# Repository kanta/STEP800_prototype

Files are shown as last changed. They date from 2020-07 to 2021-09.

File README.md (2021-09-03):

# STEP800_prototype

This repository has been retained for data storage, but is no longer being updated.

Please visit https://github.com/ponoor/STEP800.

---

STEP800

8 axis stepper motor driver board which can control over Ethernet. The current firmware is based on [Open Sound Control](http://opensoundcontrol.org/) protocol.
[Arduino Zero](https://www.arduino.cc/en/Guide/ArduinoZero) and official [Ethernet library](https://www.arduino.cc/en/reference/ethernet) compatible.

Stepper driver chips are STMicroelectronics's [L6470](https://www.st.com/en/motor-drivers/l6470.html) which provide most of functionalities as a stepper driver.

# Repository Contents

# Documentation

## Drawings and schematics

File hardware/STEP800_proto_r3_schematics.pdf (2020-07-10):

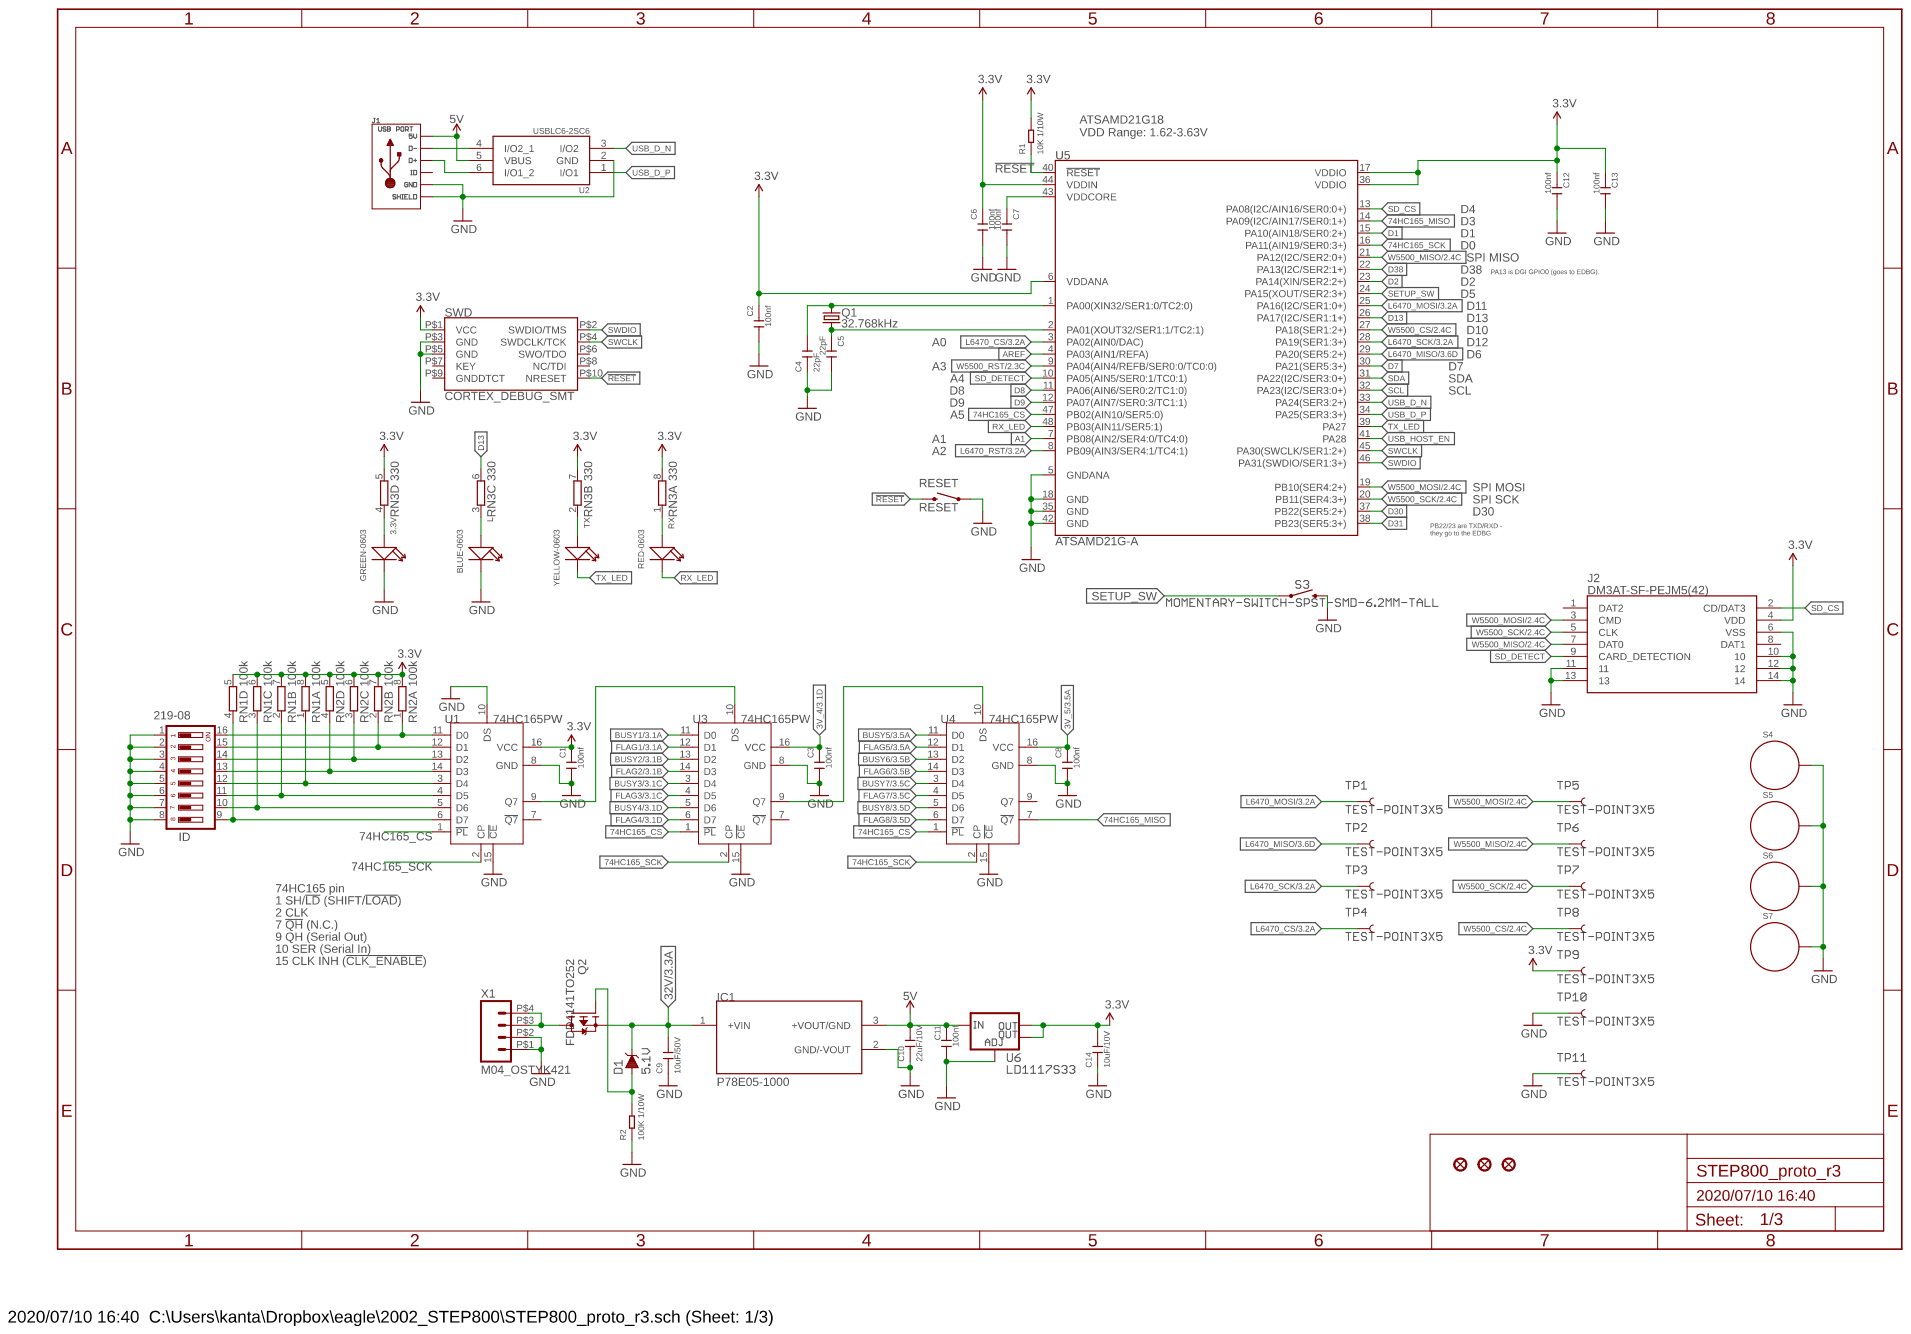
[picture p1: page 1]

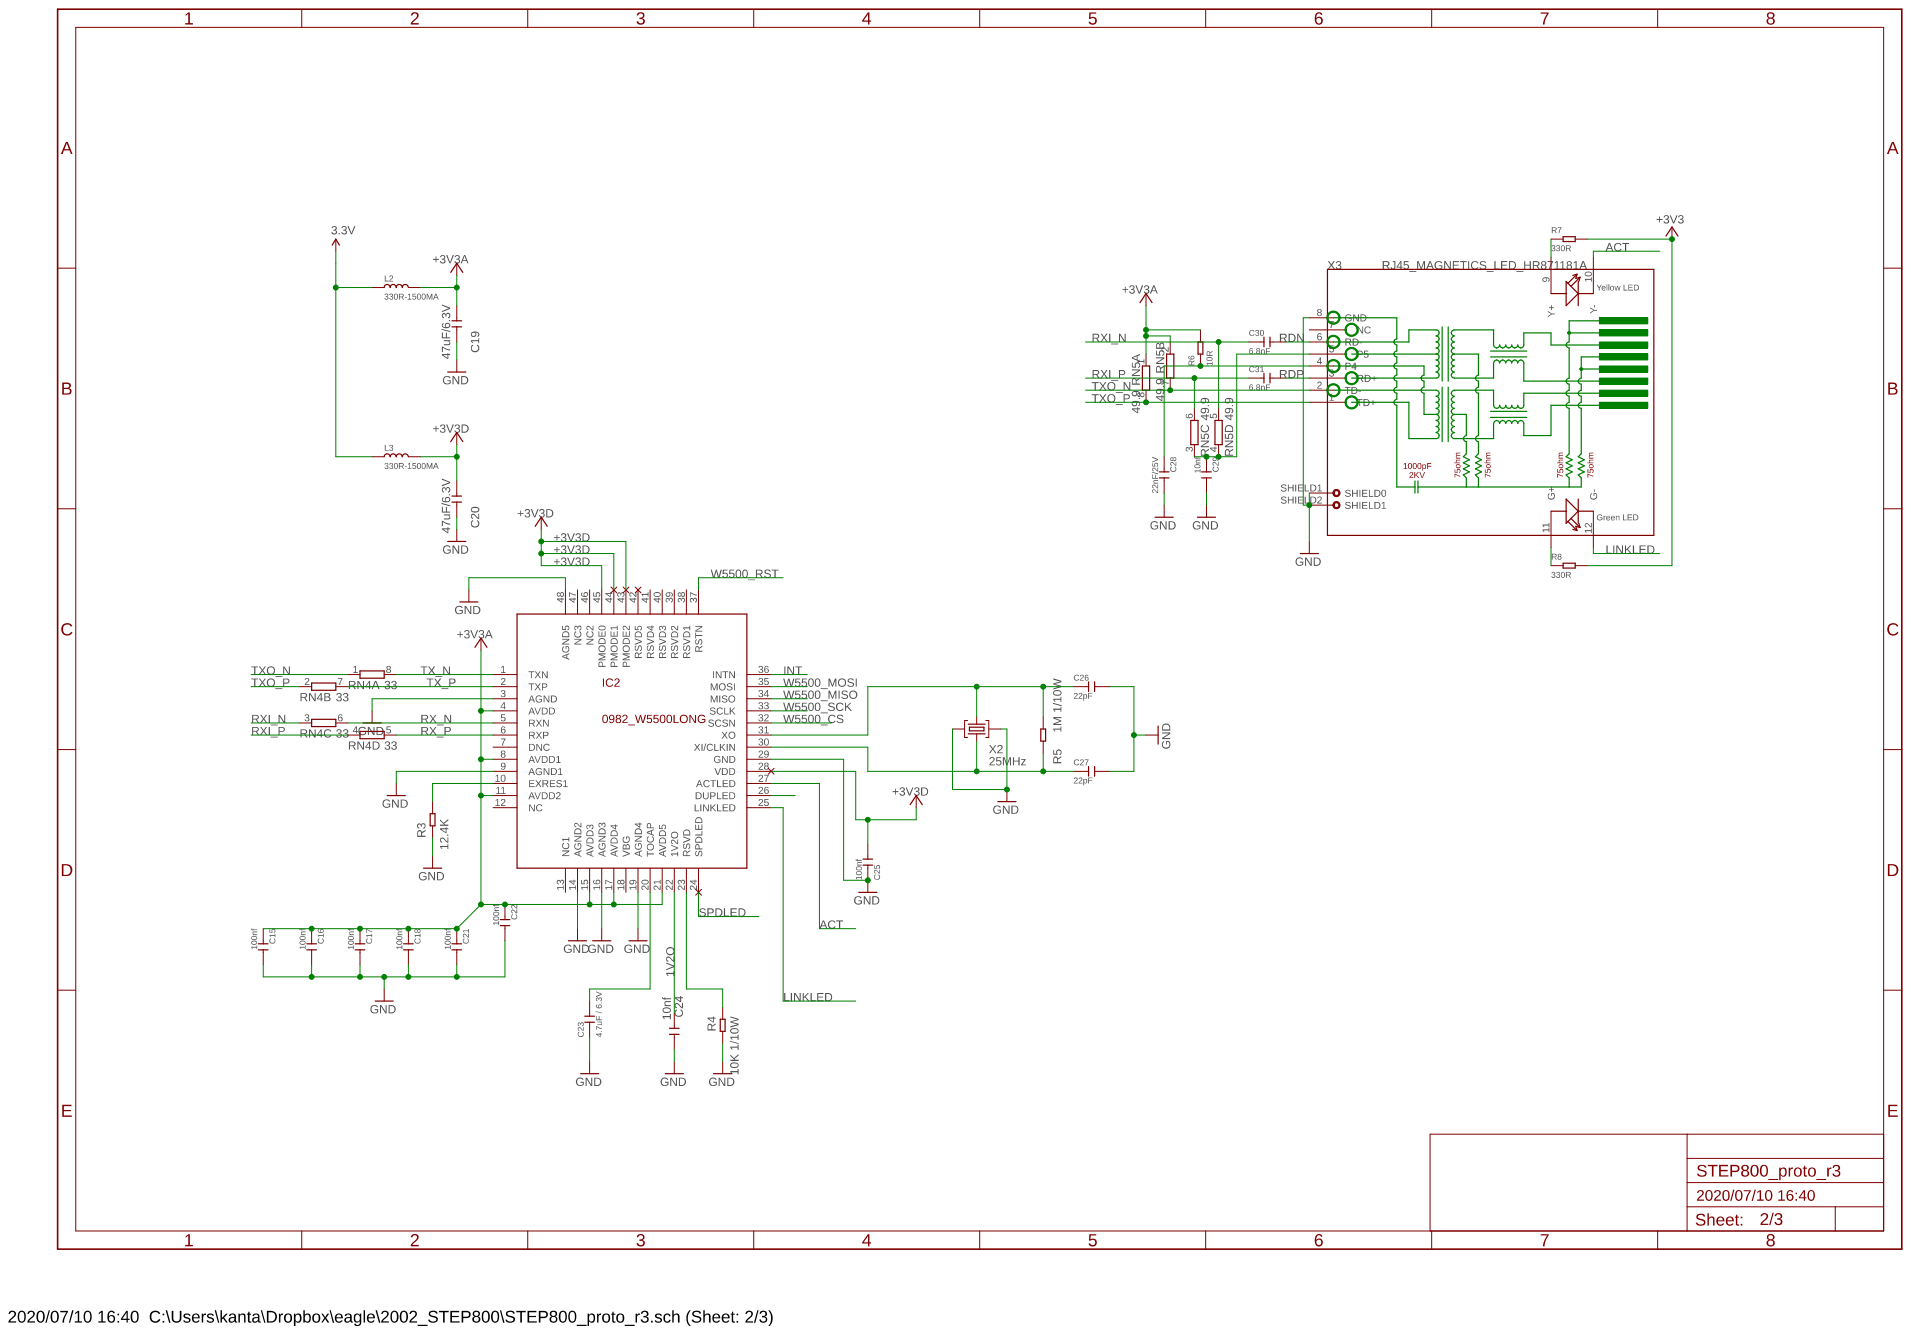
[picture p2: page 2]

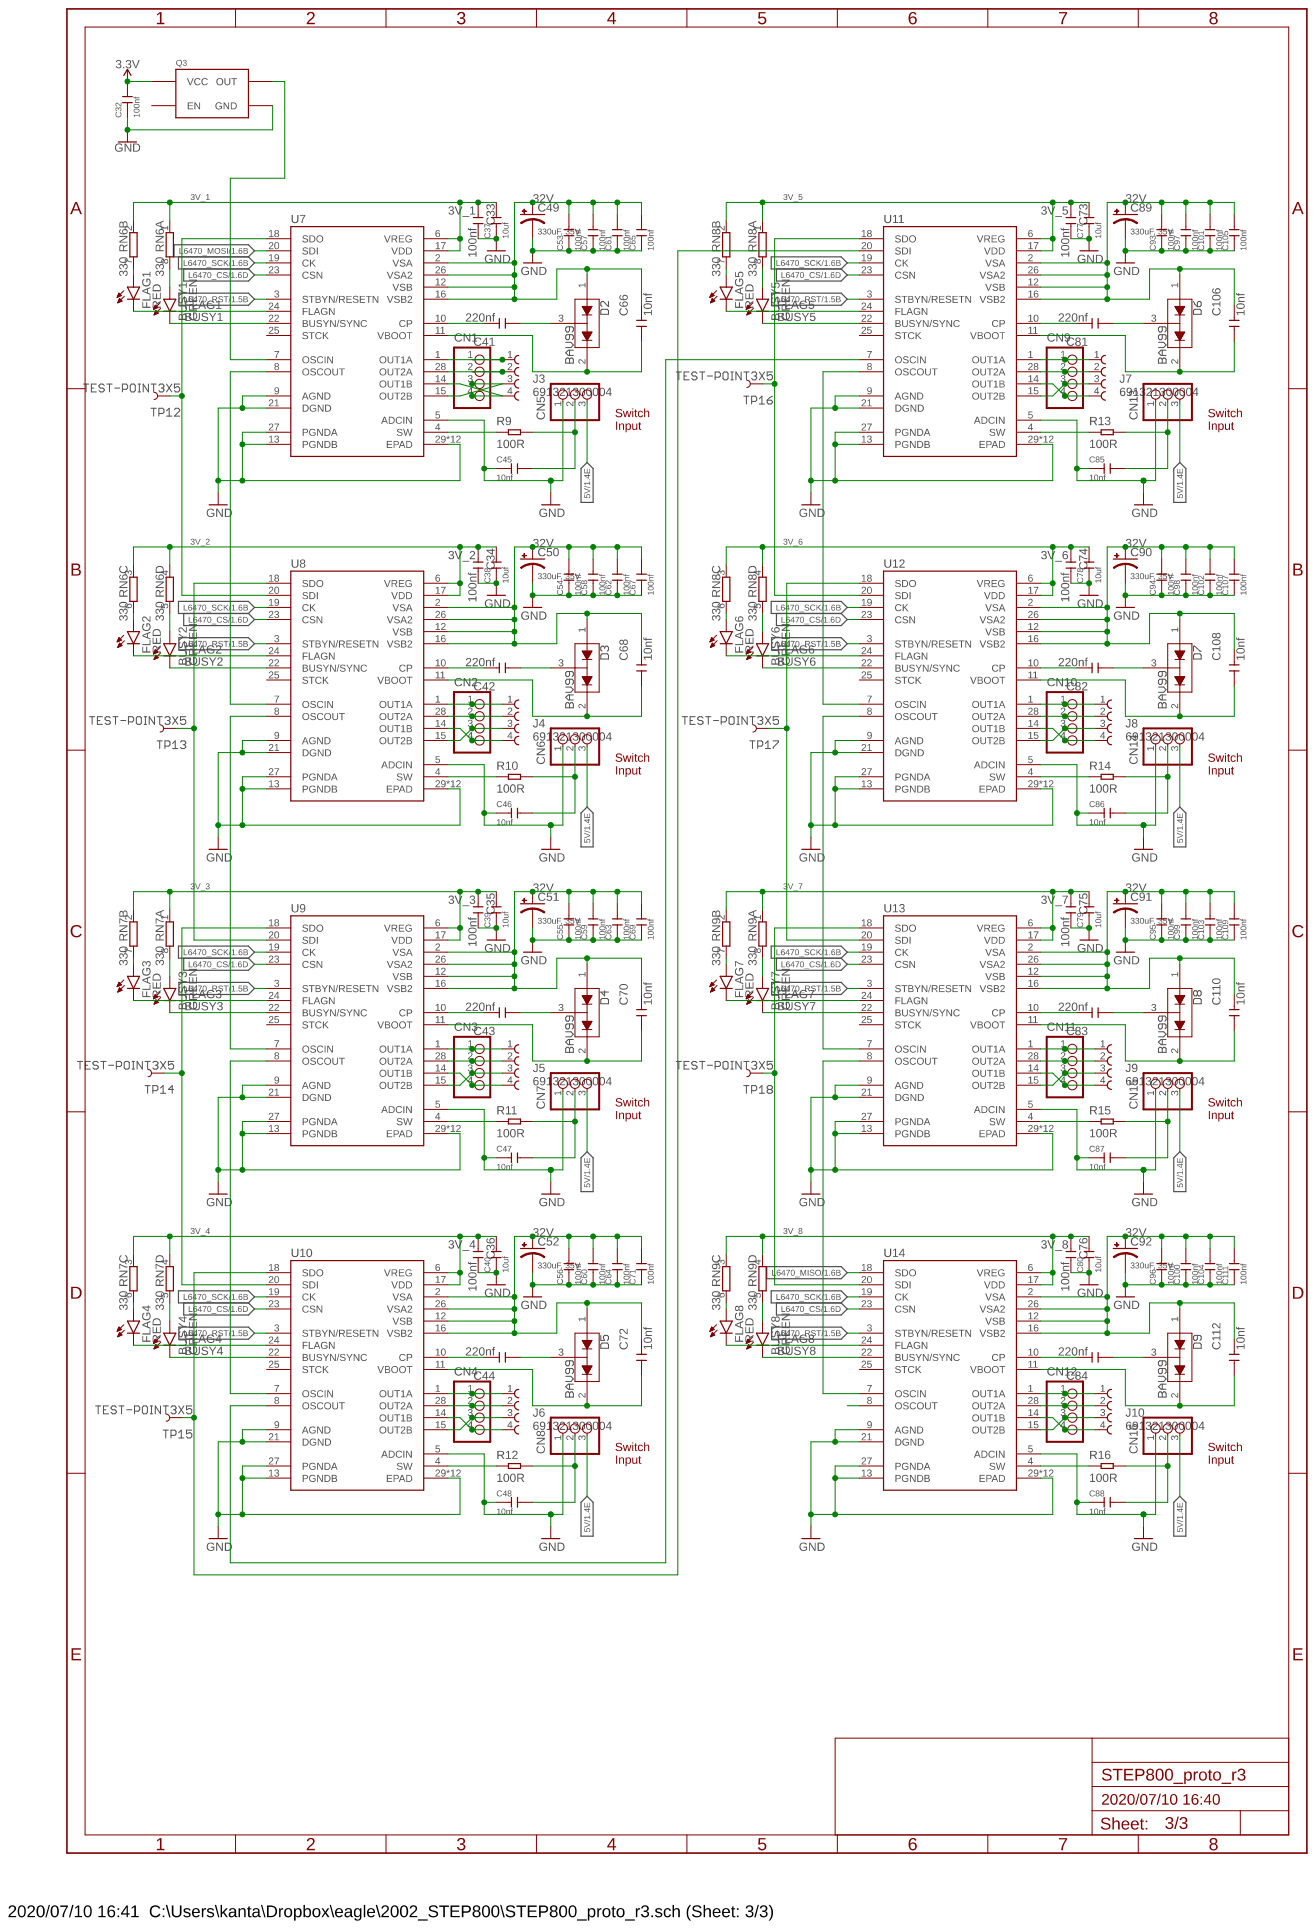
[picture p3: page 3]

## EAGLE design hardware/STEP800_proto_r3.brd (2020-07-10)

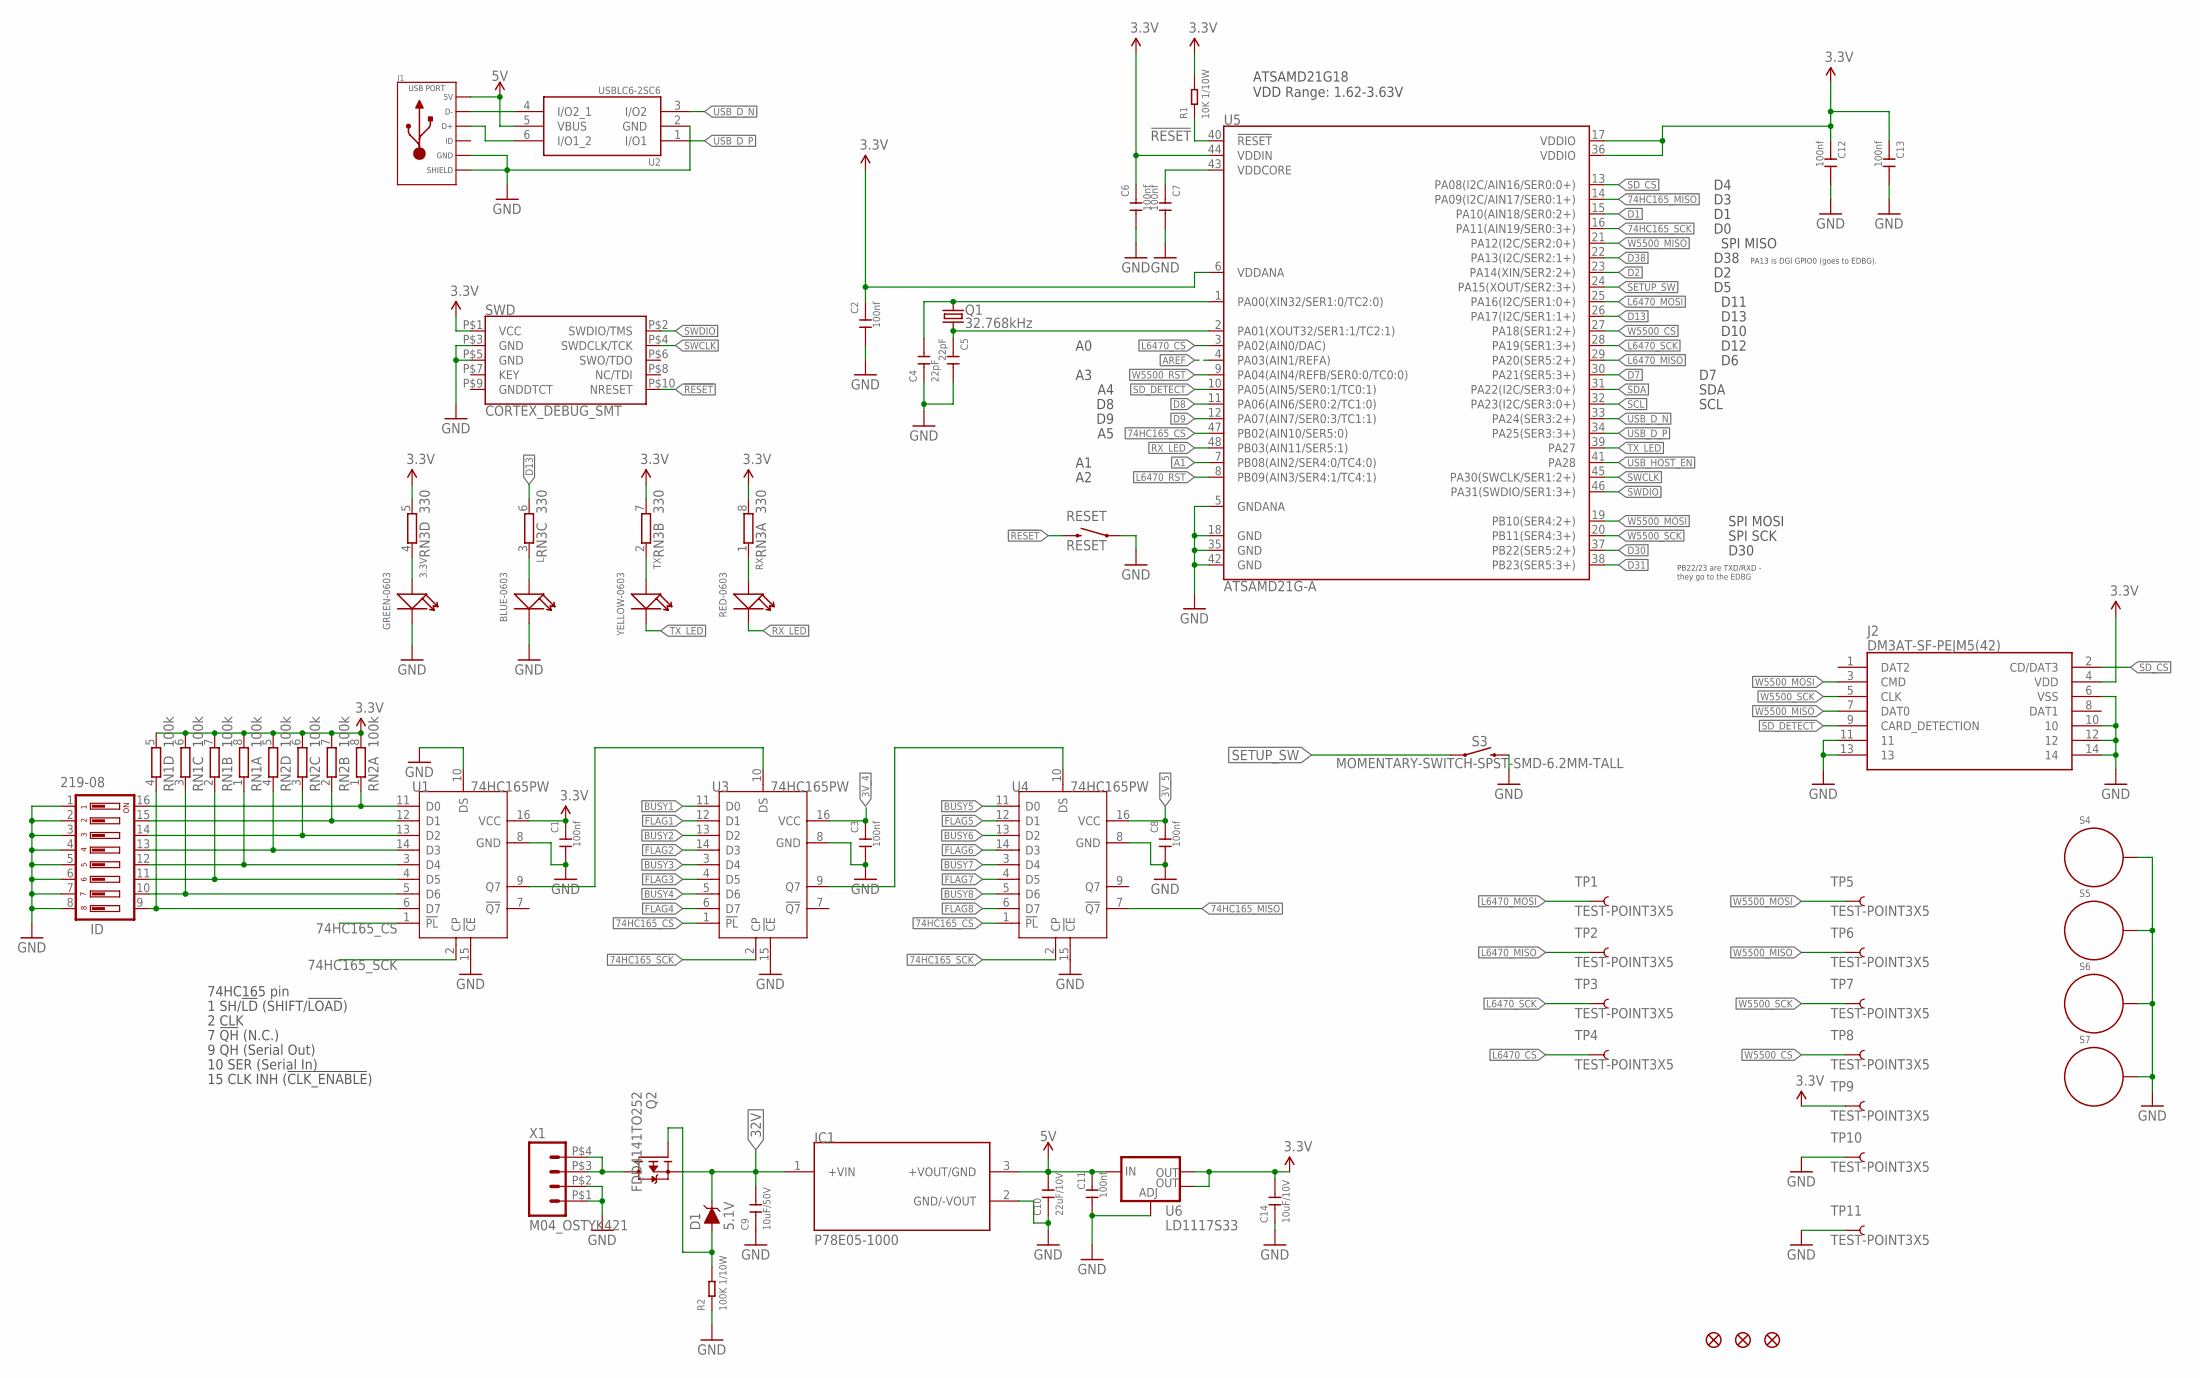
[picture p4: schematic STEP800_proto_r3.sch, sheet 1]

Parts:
3.3V: GREEN-0603; LED-0603
C1, C2, C3, C6, C7, C8, C11, C12, C13: 100nf; C0402
C4, C5: 22pF; C0402
C9: 10uF/50V; C1206
C10: 22uF/10V; C1206
C14: 10uF/10V; C0805
D1: 5.1V; SOD-323
FD1, FD2, FD3: FIDUCIAL1X2; FIDUCIAL-1X2
IC1: P78E05-1000; CONV_P78E05-1000
ID: 219-08; CTS-219-08
J1: USB_MICRO_10118193-0001LF; MICROUSB-FCI-PBAN
J2: DM3AT-SF-PEJM5(42); DM3ATSFPEJM542
L: BLUE-0603; LED-0603
Q1: 32.768kHz; FC-135
Q2: FDD4141TO252; TO252
R1: 10K 1/10W; R0603
R2: 100K 1/10W; R0603
RESET: RESET; TACTILE-SWITCH-SMD
RN1, RN2: 100k; CAY16_LONG_W
RN3: 330; CAY16_LONG_W
RX: RED-0603; LED-0603
S3: MOMENTARY-SWITCH-SPST-SMD-6.2MM-TALL; TACTILE_SWITCH_SMD_6.2MM_TALL
S4, S5, S6, S7: STANDOFF_ELECTRICAL; STANDOFF-ELECTRICAL
SWD: CORTEX_DEBUG_SMT; 20021121-00010C4LF
TP1, TP2, TP3, TP4, TP5, TP6, TP7, TP8, TP9, TP10, TP11: TEST-POINT3X5; PAD.03X.05
TX: YELLOW-0603; LED-0603
U1, U3, U4: 74HC165PW; TSSOP16
U2: USBLC6-2SC6; SOT23-6L
U5: ATSAMD21G-A; TQFP-48
U6: LD1117S33; SOT223
X1: M04_OSTYK421; OSTYK42104030

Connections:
3.3V: C1.1, C2.1, C6.1, C12.1, C13.1, C14.2, J2.4 (VDD), R1.2, RN1.5 (2), RN1.6 (2), RN1.7 (2), RN1.8 (2), RN2.5 (2), RN2.6 (2), RN2.7 (2), RN2.8 (2), RN3.5 (2), RN3.7 (2), RN3.8 (2), SWD.P$1 (VCC), TP9.P$1, U1.16 (VCC), U5.6 (VDDANA), U5.17 (VDDIO), U5.36 (VDDIO), U5.44 (VDDIN), U6.2 (OUT), U6.4 (OUT); also elsewhere on the board
3V_4: C3.1, U3.16 (VCC); also elsewhere on the board
3V_5: C8.1, U4.16 (VCC); also elsewhere on the board
5V: C10.2, C11.1, IC1.3 (+VOUT/GND), J1.1 (5V), U2.5 (VBUS), U6.3 (IN); also elsewhere on the board
32V: C9.2, D1.C, IC1.1 (+VIN), Q2.2 (S); also elsewhere on the board
74HC165_CS: U1.1 (!PL), U3.1 (!PL), U4.1 (!PL), U5.47 (PB02(AIN10/SER5:0))
74HC165_MISO: U4.7 (!Q7), U5.14 (PA09(I2C/AIN17/SER0:1+))
74HC165_SCK: U1.2 (CP), U3.2 (CP), U4.2 (CP), U5.16 (PA11(AIN19/SER0:3+))
!RESET: R1.1, RESET.3 (2), SWD.P$10 (NRESET), U5.40 (!RESET!)
A1: U5.7 (PB08(AIN2/SER4:0/TC4:0))
AREF: U5.4 (PA03(AIN1/REFA))
BUSY1: U3.11 (D0); also elsewhere on the board
BUSY2: U3.13 (D2); also elsewhere on the board
BUSY3: U3.3 (D4); also elsewhere on the board
BUSY4: U3.5 (D6); also elsewhere on the board
BUSY5: U4.11 (D0); also elsewhere on the board
BUSY6: U4.13 (D2); also elsewhere on the board
BUSY7: U4.3 (D4); also elsewhere on the board
BUSY8: U4.5 (D6); also elsewhere on the board
D1: U5.15 (PA10(AIN18/SER0:2+))
D2: U5.23 (PA14(XIN/SER2:2+))
D7: U5.30 (PA21(SER5:3+))
D8: U5.11 (PA06(AIN6/SER0:2/TC1:0))
D9: U5.12 (PA07(AIN7/SER0:3/TC1:1))
D13: RN3.6 (2), U5.26 (PA17(I2C/SER1:1+))
D30: U5.37 (PB22(SER5:2+))
D31: U5.38 (PB23(SER5:3+))
D38: U5.22 (PA13(I2C/SER2:1+))
D+1: J1.3 (D+), U2.6 (I/O1_2)
FLAG1: U3.12 (D1); also elsewhere on the board
FLAG2: U3.14 (D3); also elsewhere on the board
FLAG3: U3.4 (D5); also elsewhere on the board
FLAG4: U3.6 (D7); also elsewhere on the board
FLAG5: U4.12 (D1); also elsewhere on the board
FLAG6: U4.14 (D3); also elsewhere on the board
FLAG7: U4.4 (D5); also elsewhere on the board
FLAG8: U4.6 (D7); also elsewhere on the board
GND: 3.3V.-, C1.2, C2.2, C3.2, C4.1, C5.2, C6.2, C7.2, C8.2, C9.1, C10.1, C11.2, C12.2, C13.2, C14.1, IC1.2 (GND/-VOUT), ID.1, ID.2, ID.3, ID.4, ID.5, ID.6, ID.7, ID.8, J1.5 (GND), J1.S1 (SLD), J1.S2 (SLD), J1.S3 (SLD), J1.S4 (SLD), J1.S5 (SLD), J1.S6 (SLD), J1.S7 (SLD), J1.S8 (SLD), J2.6 (VSS), J2.10, J2.11, J2.12, J2.13, J2.14, L.-, R2.1, RESET.1, S3.B2 (2), S4.P1, S5.P1, S6.P1, S7.P1, SWD.P$3 (GND), SWD.P$5 (GND), TP10.P$1, TP11.P$1, U1.8 (GND), U1.10 (DS), U1.15 (!CE), U2.2 (GND), U3.8 (GND), U3.15 (!CE), U4.8 (GND), U4.15 (!CE), U5.5 (GNDANA), U5.18 (GND), U5.35 (GND), U5.42 (GND), U6.1 (ADJ), X1.P$1 (1), X1.P$2 (2); also elsewhere on the board
L6470_CS: TP4.P$1, U5.3 (PA02(AIN0/DAC)); also elsewhere on the board
L6470_MISO: TP2.P$1, U5.29 (PA20(SER5:2+)); also elsewhere on the board
L6470_MOSI: TP1.P$1, U5.25 (PA16(I2C/SER1:0+)); also elsewhere on the board
L6470_RST: U5.8 (PB09(AIN3/SER4:1/TC4:1)); also elsewhere on the board
L6470_SCK: TP3.P$1, U5.28 (PA19(SER1:3+)); also elsewhere on the board
unnamed: C4.2, Q1.P$2 (2), U5.1 (PA00(XIN32/SER1:0/TC2:0))
unnamed: ID.16, RN2.1, U1.11 (D0)
unnamed: D1.A, Q2.1 (G), R2.2
unnamed: ID.15, RN2.2 (1), U1.12 (D1)
unnamed: ID.14, RN2.3 (1), U1.13 (D2)
unnamed: C5.1, Q1.P$1 (1), U5.2 (PA01(XOUT32/SER1:1/TC2:1))
unnamed: U1.9 (Q7), U3.10 (DS)
unnamed: RN3.1, RX.+
unnamed: ID.13, RN2.4 (1), U1.14 (D3)
unnamed: ID.12, RN1.1, U1.3 (D4)
unnamed: ID.11, RN1.2 (1), U1.4 (D5)
unnamed: RN3.2 (1), TX.+
unnamed: L.+, RN3.3 (1)
unnamed: 3.3V.+, RN3.4 (1)
unnamed: J1.2 (D-), U2.4 (I/O2_1)
unnamed: ID.10, RN1.3 (1), U1.5 (D6)
unnamed: U3.9 (Q7), U4.10 (DS)
unnamed: ID.9, RN1.4 (1), U1.6 (D7)
RX_LED: RX.-, U5.48 (PB03(AIN11/SER5:1))
SCL: U5.32 (PA23(I2C/SER3:0+))
SDA: U5.31 (PA22(I2C/SER3:0+))
SD_CS: J2.2 (CD/DAT3), U5.13 (PA08(I2C/AIN16/SER0:0+))
SD_DETECT: J2.9 (CARD_DETECTION), U5.10 (PA05(AIN5/SER0:1/TC0:1))
SETUP_SW: S3.A2 (1), U5.24 (PA15(XOUT/SER2:3+))
SWCLK: SWD.P$4 (SWDCLK/TCK), U5.45 (PA30(SWCLK/SER1:2+))
SWDIO: SWD.P$2 (SWDIO/TMS), U5.46 (PA31(SWDIO/SER1:3+))
TX_LED: TX.-, U5.39 (PA27)
USB_D_N: U2.3 (I/O2), U5.33 (PA24(SER3:2+))
USB_D_P: U2.1 (I/O1), U5.34 (PA25(SER3:3+))
USB_HOST_EN: U5.41 (PA28)
VDDCORE1: C7.1, U5.43 (VDDCORE)
VRAW: Q2.3 (D), X1.P$3 (3), X1.P$4 (4)
W5500_CS: TP8.P$1, U5.27 (PA18(SER1:2+)); also elsewhere on the board
W5500_MISO: J2.7 (DAT0), TP6.P$1, U5.21 (PA12(I2C/SER2:0+)); also elsewhere on the board
W5500_MOSI: J2.3 (CMD), TP5.P$1, U5.19 (PB10(SER4:2+)); also elsewhere on the board
W5500_RST: U5.9 (PA04(AIN4/REFB/SER0:0/TC0:0)); also elsewhere on the board
W5500_SCK: J2.5 (CLK), TP7.P$1, U5.20 (PB11(SER4:3+)); also elsewhere on the board

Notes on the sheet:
PB22/23 are TXD/RXD - they go to the EDBG
PA13 is DGI GPIO0 (goes to EDBG).
ATSAMD21G18 VDD Range: 1.62-3.63V
D30
D12
D10
D11
D13
D38
SPI MISO
SPI MOSI
SPI SCK
SDA
SCL
1 SH/!LD! (SHIFT/!LOAD!)
2 CLK
7 !QH! (N.C.)
9 QH (Serial Out)
10 SER (Serial In)
15 CLK INH (!CLK_ENABLE!)
74HC165 pin

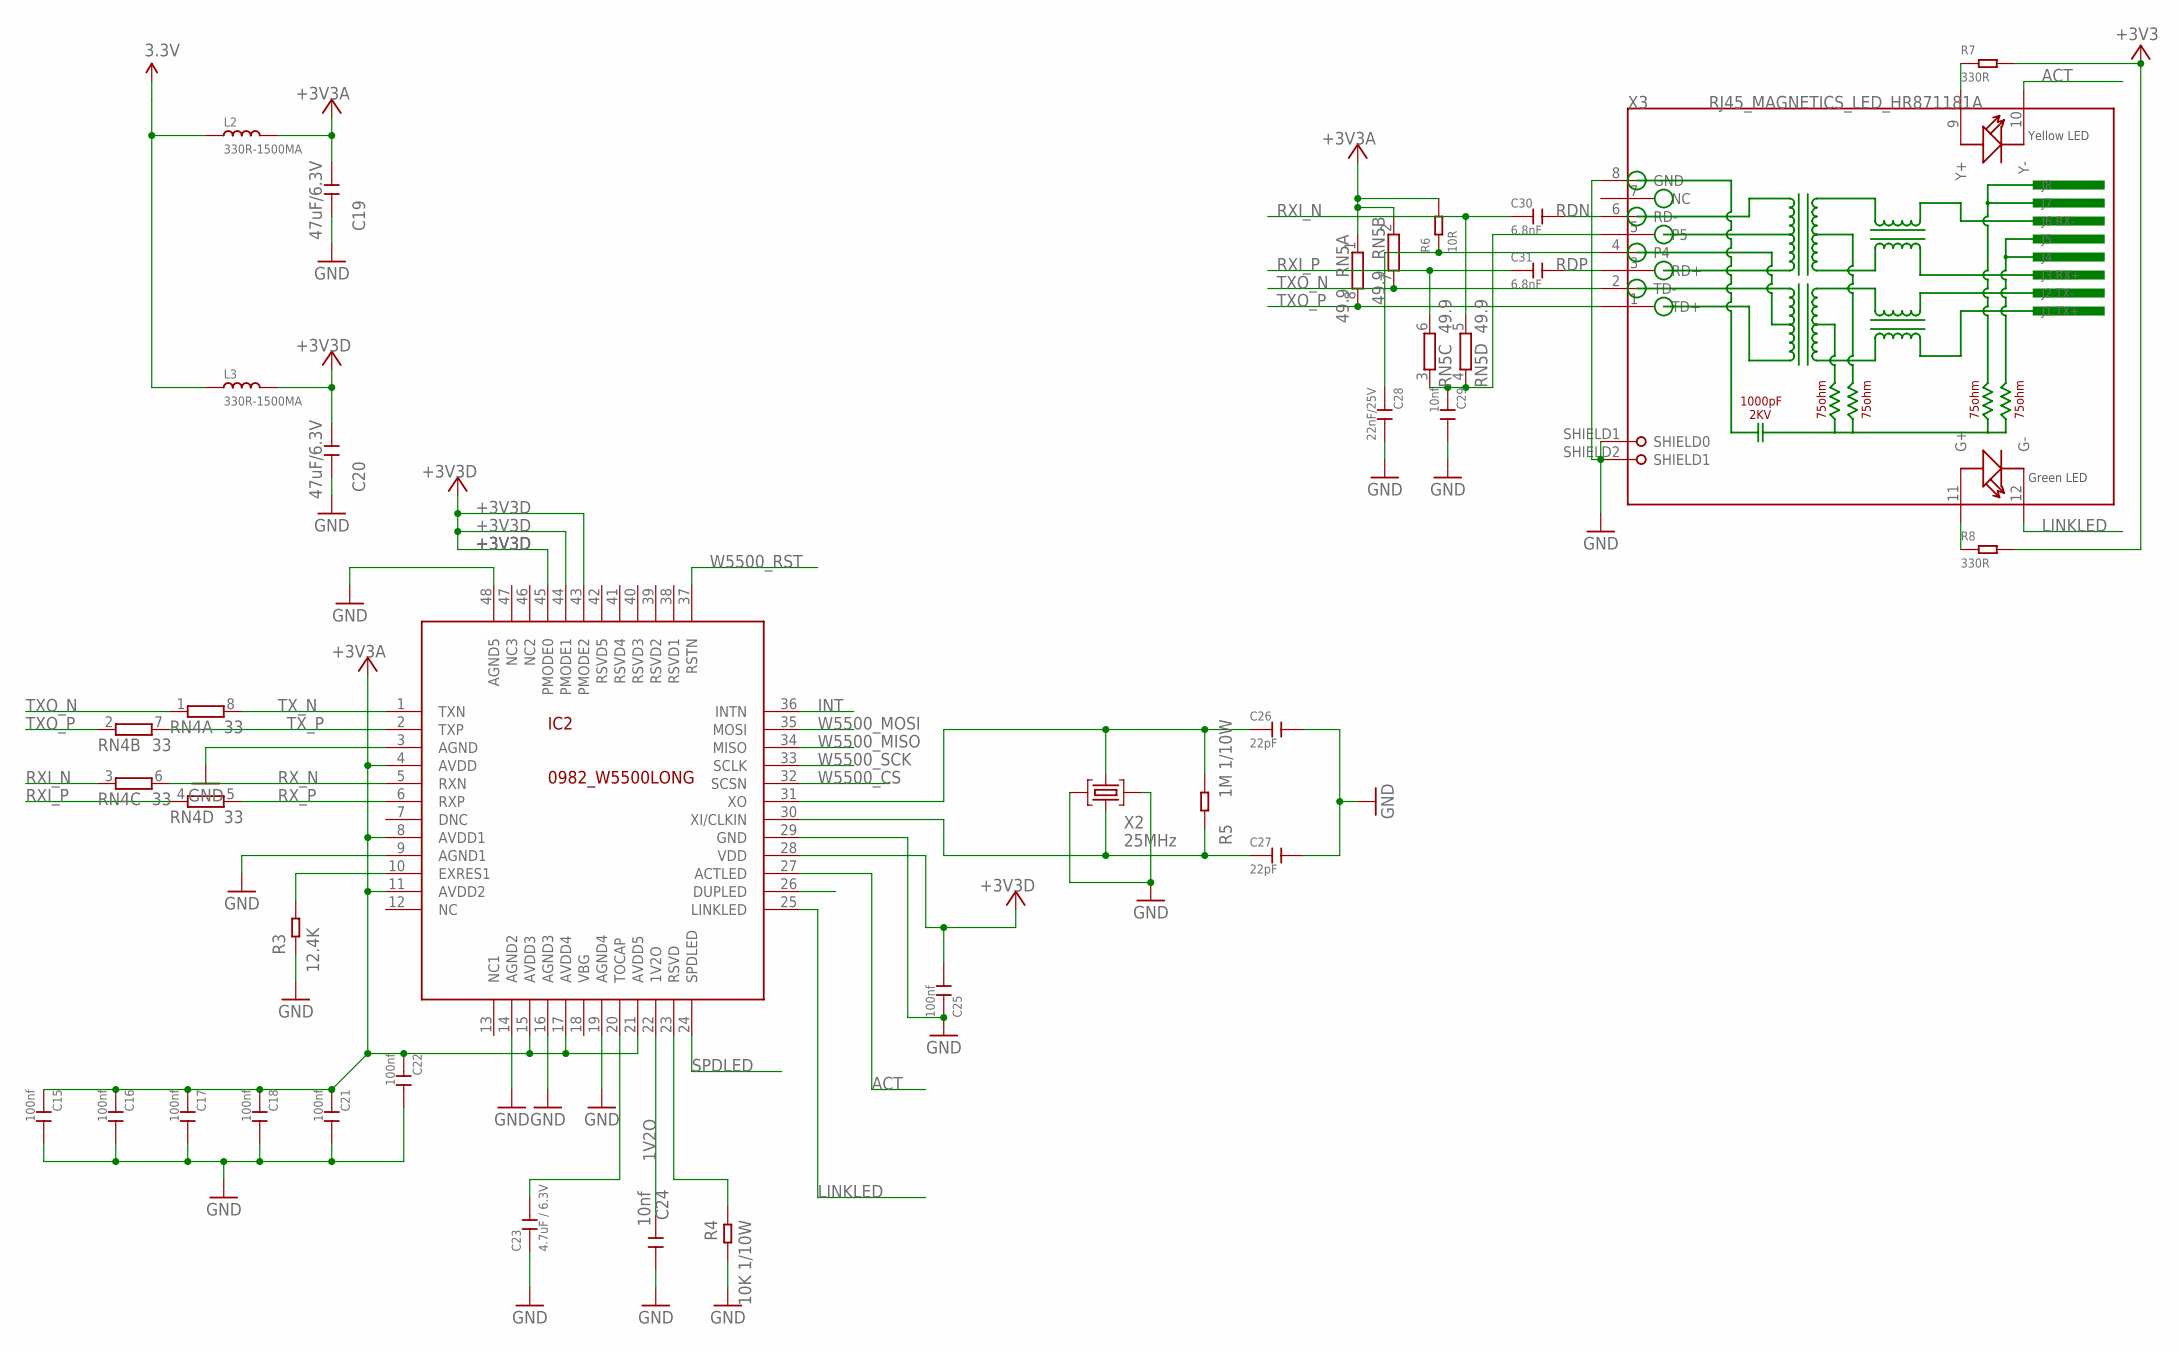
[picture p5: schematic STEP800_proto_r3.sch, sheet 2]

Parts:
C15, C16, C17, C18, C21, C22, C25: 100nf; C0402
C19, C20: 47uF/6.3V; C1206
C23: 4.7uF / 6.3V; C0603
C24, C29: 10nf; C0402
C26, C27: 22pF; C0402
C28: 22nF/25V; C0402
C30, C31: 6.8nF; C0402
IC2: 0982_W5500LONG; TQFP48-LONG
L2, L3: 330R-1500MA; L0805
R3: 12.4K; R0603
R4: 10K 1/10W; R0603
R5: 1M 1/10W; R0603
R6: 10R; R0603
R7, R8: 330R; R0603
RN4: 33; CAY16_LONG_W
RN5: 49.9; CAY16_LONG_W
X2: 25MHz; CRYSTAL-3.2-2.5
X3: RJ45_MAGNETICS_LED_HR871181A; HR871181A

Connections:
1V2O: C24.2, IC2.22 (1V2O)
3.3V: L2.1, L3.1, R7.2, R8.2; also elsewhere on the board
+3V3A: C15.1, C16.1, C17.1, C18.1, C19.1, C21.1, C22.1, IC2.4 (AVDD), IC2.8 (AVDD1), IC2.11 (AVDD2), IC2.15 (AVDD3), IC2.17 (AVDD4), IC2.21 (AVDD5), L2.2, R6.2, RN5.1, RN5.2 (1)
+3V3D: C20.1, C25.2, IC2.28 (VDD), IC2.43 (PMODE2), IC2.44 (PMODE1), IC2.45 (PMODE0), L3.2
ACT: IC2.27 (ACTLED), X3.10 (Y-)
FDXLED1: IC2.26 (DUPLED)
GND: C15.2, C16.2, C17.2, C18.2, C19.2, C20.2, C21.2, C22.2, C23.1, C24.1, C25.1, C26.2, C27.2, C28.2, C29.2, IC2.3 (AGND), IC2.9 (AGND1), IC2.14 (AGND2), IC2.16 (AGND3), IC2.19 (AGND4), IC2.29 (GND), IC2.48 (AGND5), R3.1, R4.1, X2.2 (GND), X2.4 (GND), X3.8 (GND), X3.SHIELD1 (SHIELD0), X3.SHIELD2 (SHIELD1); also elsewhere on the board
INT: IC2.36 (INTN)
LINKLED: IC2.25 (LINKLED), X3.12 (G-)
unnamed: C26.1, IC2.31 (XO), R5.1, X2.3 (C2)
unnamed: IC2.23 (RSVD), R4.2
unnamed: IC2.10 (EXRES1), R3.2
unnamed: C23.2, IC2.20 (TOCAP)
unnamed: C28.1, R6.1, X3.4
unnamed: C29.1, RN5.3 (1), RN5.4 (1), X3.5
unnamed: R7.1, X3.9 (Y+)
unnamed: R8.1, X3.11 (G+)
NC: IC2.12 (NC)
OSC2E1: C27.1, IC2.30 (XI/CLKIN), R5.2, X2.1 (C1)
RDN: C30.2, X3.6 (RD-)
RDP: C31.2, X3.3 (RD+)
RSVD1: IC2.38 (RSVD1)
RSVD2: IC2.39 (RSVD2)
RSVD3: IC2.40 (RSVD3)
RXI_N: C30.1, RN4.3 (1), RN5.5 (2)
RXI_P: C31.1, RN4.4 (1), RN5.6 (2)
RX_N: IC2.5 (RXN), RN4.6 (2)
RX_P: IC2.6 (RXP), RN4.5 (2)
SPDLED: IC2.24 (SPDLED)
TXO_N: RN4.1, RN5.7 (2), X3.2 (TD-)
TXO_P: RN4.2 (1), RN5.8 (2), X3.1 (TD+)
TX_N: IC2.1 (TXN), RN4.8 (2)
TX_P: IC2.2 (TXP), RN4.7 (2)
W5500_CS: IC2.32 (SCSN); also elsewhere on the board
W5500_MISO: IC2.34 (MISO); also elsewhere on the board
W5500_MOSI: IC2.35 (MOSI); also elsewhere on the board
W5500_RST: IC2.37 (RSTN); also elsewhere on the board
W5500_SCK: IC2.33 (SCLK); also elsewhere on the board

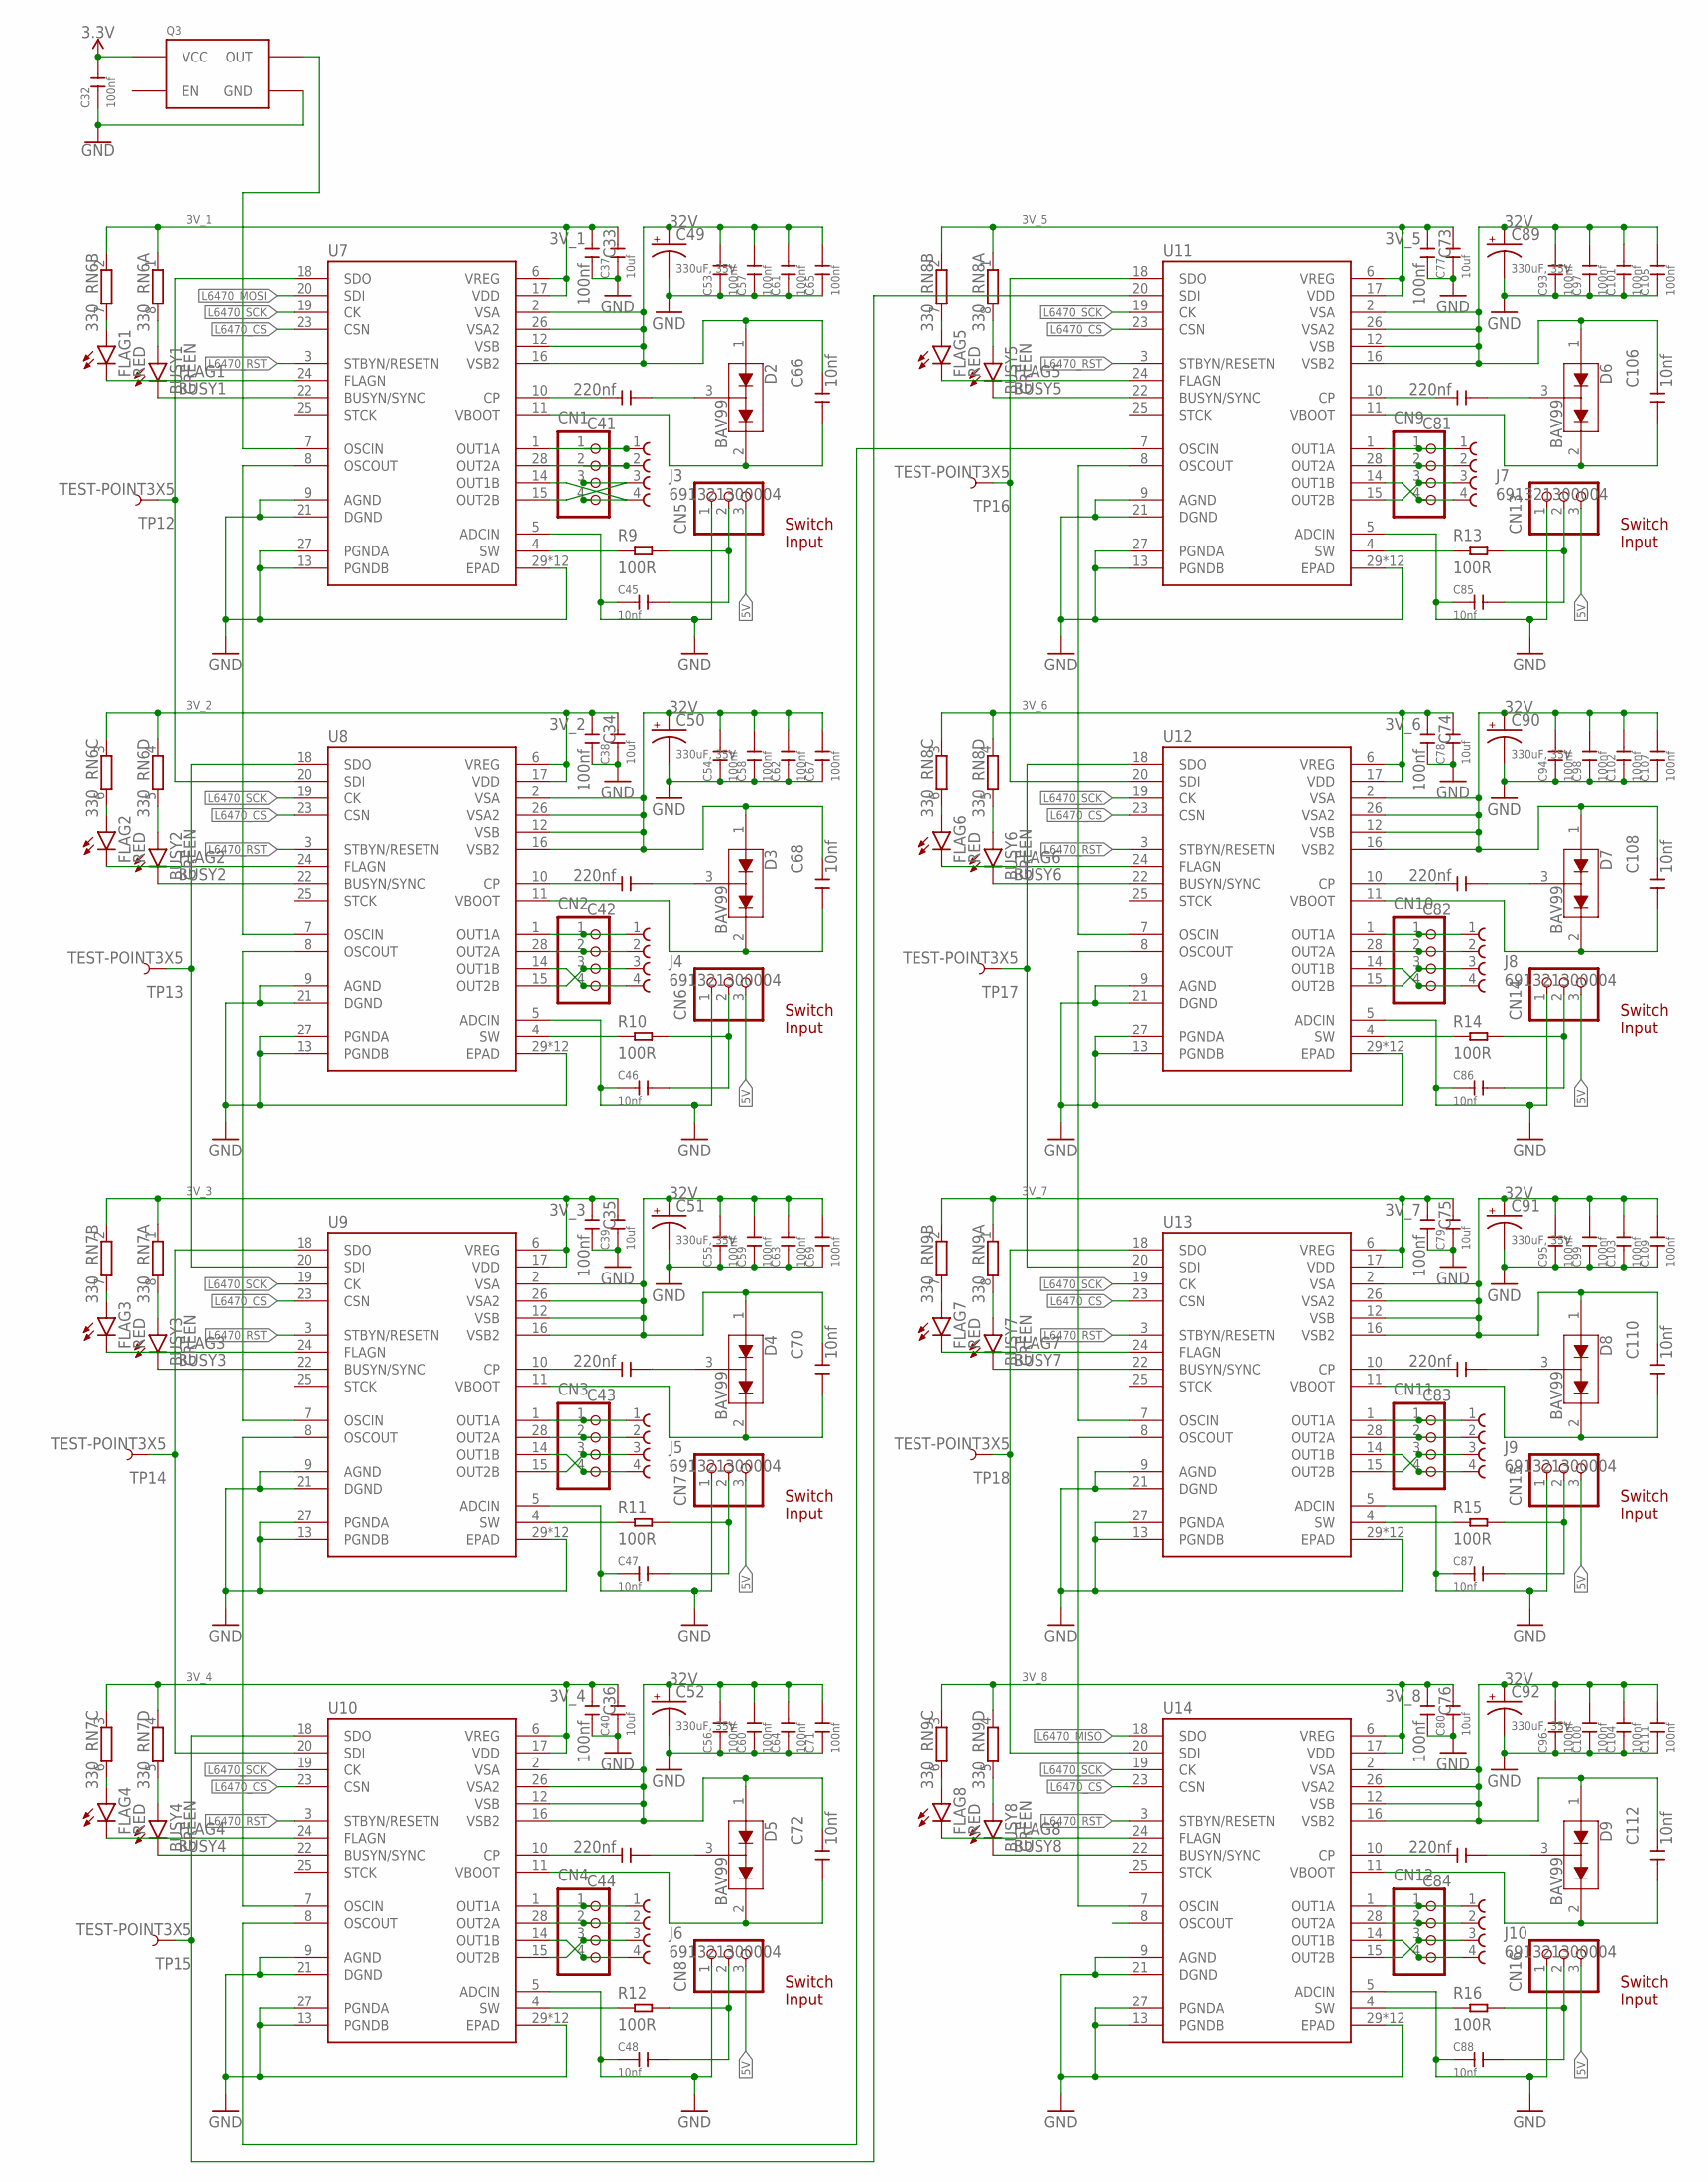
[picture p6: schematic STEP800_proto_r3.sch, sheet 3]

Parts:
BUSY1, BUSY2, BUSY3, BUSY4, BUSY5, BUSY6, BUSY7, BUSY8: GREEN; LED-0603
C32, C33, C34, C35, C36, C73, C74, C75, C76: 100nf; C0402
C37, C38, C39, C40, C77, C78, C79, C80: 10uf; C0805
C41, C42, C43, C44, C81, C82, C83, C84: 220nf; C0603
C45, C46, C47, C48, C66, C68, C70, C72, C85, C86, C87, C88, C106, C108, C110, C112: 10nf; C0402
C49, C50, C51, C52, C89, C90, C91, C92: 330uF, 35V; NICHICON_D10
C53, C54, C55, C56, C57, C58, C59, C60, C61, C62, C63, C64, C65, C67, C69, C71, C93, C94, C95, C96, C97, C98, C99, C100, C101, C102, C103, C104, C105, C107, C109, C111: 100nf; C0603
CN1, CN2, CN3, CN4, CN9, CN10, CN11, CN12: B4B-XASK-1
CN5, CN6, CN7, CN8, CN13, CN14, CN15, CN16: B3B-XASK-1
D2, D3, D4, D5, D6, D7, D8, D9: BAV99; SOT23-3
FLAG1, FLAG2, FLAG3, FLAG4, FLAG5, FLAG6, FLAG7, FLAG8: RED; LED-0603
J3, J4, J5, J6, J7, J8, J9, J10: 691321300004
Q3: CRYSTAL_OSC_SG5032; SG5032
R9, R10, R11, R12, R13, R14, R15, R16: 100R; R0603
RN6, RN7, RN8, RN9: 330; CAY16_LONG_W
TP12, TP13, TP14, TP15, TP16, TP17, TP18: TEST-POINT3X5; PAD.03X.05
U7, U8, U9, U10, U11, U12, U13, U14: L6470_THERMALVIA; HTSSOP28_VIA

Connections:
3.3V: C32.2, Q3.4 (VCC); also elsewhere on the board
3V_1: C33.1, C37.2, RN6.1, RN6.2 (1), U7.6 (VREG), U7.17 (VDD)
3V_2: C34.1, C38.2, RN6.3 (1), RN6.4 (1), U8.6 (VREG), U8.17 (VDD)
3V_3: C35.1, C39.2, RN7.1, RN7.2 (1), U9.6 (VREG), U9.17 (VDD)
3V_4: C36.1, C40.2, RN7.3 (1), RN7.4 (1), U10.6 (VREG), U10.17 (VDD); also elsewhere on the board
3V_5: C73.1, C77.2, RN8.1, RN8.2 (1), U11.6 (VREG), U11.17 (VDD); also elsewhere on the board
3V_6: C74.1, C78.2, RN8.3 (1), RN8.4 (1), U12.6 (VREG), U12.17 (VDD)
3V_7: C75.1, C79.2, RN9.1, RN9.2 (1), U13.6 (VREG), U13.17 (VDD)
3V_8: C76.1, C80.2, RN9.3 (1), RN9.4 (1), U14.6 (VREG), U14.17 (VDD)
5V: CN5.3, CN6.3, CN7.3, CN8.3, CN13.3, CN14.3, CN15.3, CN16.3; also elsewhere on the board
32V: C49.+, C50.+, C51.+, C52.+, C53.2, C54.2, C55.2, C56.2, C57.2, C58.2, C59.2, C60.2, C61.2, C62.2, C63.2, C64.2, C65.2, C66.2, C67.2, C68.2, C69.2, C70.2, C71.2, C72.2, C89.+, C90.+, C91.+, C92.+, C93.2, C94.2, C95.2, C96.2, C97.2, C98.2, C99.2, C100.2, C101.2, C102.2, C103.2, C104.2, C105.2, C106.2, C107.2, C108.2, C109.2, C110.2, C111.2, C112.2, D2.1 (A1), D3.1 (A1), D4.1 (A1), D5.1 (A1), D6.1 (A1), D7.1 (A1), D8.1 (A1), D9.1 (A1), U7.2 (VSA), U7.12 (VSB), U7.16 (VSB2), U7.26 (VSA2), U8.2 (VSA), U8.12 (VSB), U8.16 (VSB2), U8.26 (VSA2), U9.2 (VSA), U9.12 (VSB), U9.16 (VSB2), U9.26 (VSA2), U10.2 (VSA), U10.12 (VSB), U10.16 (VSB2), U10.26 (VSA2), U11.2 (VSA), U11.12 (VSB), U11.16 (VSB2), U11.26 (VSA2), U12.2 (VSA), U12.12 (VSB), U12.16 (VSB2), U12.26 (VSA2), U13.2 (VSA), U13.12 (VSB), U13.16 (VSB2), U13.26 (VSA2), U14.2 (VSA), U14.12 (VSB), U14.16 (VSB2), U14.26 (VSA2); also elsewhere on the board
BUSY1: BUSY1.C, U7.22 (BUSYN/SYNC); also elsewhere on the board
BUSY2: BUSY2.C, U8.22 (BUSYN/SYNC); also elsewhere on the board
BUSY3: BUSY3.C, U9.22 (BUSYN/SYNC); also elsewhere on the board
BUSY4: BUSY4.C, U10.22 (BUSYN/SYNC); also elsewhere on the board
BUSY5: BUSY5.C, U11.22 (BUSYN/SYNC); also elsewhere on the board
BUSY6: BUSY6.C, U12.22 (BUSYN/SYNC); also elsewhere on the board
BUSY7: BUSY7.C, U13.22 (BUSYN/SYNC); also elsewhere on the board
BUSY8: BUSY8.C, U14.22 (BUSYN/SYNC); also elsewhere on the board
FLAG1: FLAG1.C, U7.24 (FLAGN); also elsewhere on the board
FLAG2: FLAG2.C, U8.24 (FLAGN); also elsewhere on the board
FLAG3: FLAG3.C, U9.24 (FLAGN); also elsewhere on the board
FLAG4: FLAG4.C, U10.24 (FLAGN); also elsewhere on the board
FLAG5: FLAG5.C, U11.24 (FLAGN); also elsewhere on the board
FLAG6: FLAG6.C, U12.24 (FLAGN); also elsewhere on the board
FLAG7: FLAG7.C, U13.24 (FLAGN); also elsewhere on the board
FLAG8: FLAG8.C, U14.24 (FLAGN); also elsewhere on the board
GND: C32.1, C33.2, C34.2, C35.2, C36.2, C37.1, C38.1, C39.1, C40.1, C45.1, C46.1, C47.1, C48.1, C49.-, C50.-, C51.-, C52.-, C53.1, C54.1, C55.1, C56.1, C57.1, C58.1, C59.1, C60.1, C61.1, C62.1, C63.1, C64.1, C65.1, C67.1, C69.1, C71.1, C73.2, C74.2, C75.2, C76.2, C77.1, C78.1, C79.1, C80.1, C85.1, C86.1, C87.1, C88.1, C89.-, C90.-, C91.-, C92.-, C93.1, C94.1, C95.1, C96.1, C97.1, C98.1, C99.1, C100.1, C101.1, C102.1, C103.1, C104.1, C105.1, C107.1, C109.1, C111.1, CN5.1, CN6.1, CN7.1, CN8.1, CN13.1, CN14.1, CN15.1, CN16.1, Q3.2 (GND), U7.5 (ADCIN), U7.9 (AGND), U7.13 (PGNDB), U7.21 (DGND), U7.27 (PGNDA), U7.29 (EPAD), U7.VIA1 (EPAD), U7.VIA2 (EPAD), U7.VIA3 (EPAD), U7.VIA4 (EPAD), U7.VIA5 (EPAD), U7.VIA6 (EPAD), U7.VIA7 (EPAD), U7.VIA8 (EPAD), U7.VIA9 (EPAD), U7.VIA10 (EPAD), U7.VIA11 (EPAD), U8.5 (ADCIN), U8.9 (AGND), U8.13 (PGNDB), U8.21 (DGND), U8.27 (PGNDA), U8.29 (EPAD), U8.VIA1 (EPAD), U8.VIA2 (EPAD), U8.VIA3 (EPAD), U8.VIA4 (EPAD), U8.VIA5 (EPAD), U8.VIA6 (EPAD), U8.VIA7 (EPAD), U8.VIA8 (EPAD), U8.VIA9 (EPAD), U8.VIA10 (EPAD), U8.VIA11 (EPAD), U9.5 (ADCIN), U9.9 (AGND), U9.13 (PGNDB), U9.21 (DGND), U9.27 (PGNDA), U9.29 (EPAD), U9.VIA1 (EPAD), U9.VIA2 (EPAD), U9.VIA3 (EPAD), U9.VIA4 (EPAD), U9.VIA5 (EPAD), U9.VIA6 (EPAD), U9.VIA7 (EPAD), U9.VIA8 (EPAD), U9.VIA9 (EPAD), U9.VIA10 (EPAD), U9.VIA11 (EPAD), U10.5 (ADCIN), U10.9 (AGND), U10.13 (PGNDB), U10.21 (DGND), U10.27 (PGNDA), U10.29 (EPAD), U10.VIA1 (EPAD), U10.VIA2 (EPAD), U10.VIA3 (EPAD), U10.VIA4 (EPAD), U10.VIA5 (EPAD), U10.VIA6 (EPAD), U10.VIA7 (EPAD), U10.VIA8 (EPAD), U10.VIA9 (EPAD), U10.VIA10 (EPAD), U10.VIA11 (EPAD), U11.5 (ADCIN), U11.9 (AGND), U11.13 (PGNDB), U11.21 (DGND), U11.27 (PGNDA), U11.29 (EPAD), U11.VIA1 (EPAD), U11.VIA2 (EPAD), U11.VIA3 (EPAD), U11.VIA4 (EPAD), U11.VIA5 (EPAD), U11.VIA6 (EPAD), U11.VIA7 (EPAD), U11.VIA8 (EPAD), U11.VIA9 (EPAD), U11.VIA10 (EPAD), U11.VIA11 (EPAD), U12.5 (ADCIN), U12.9 (AGND), U12.13 (PGNDB), U12.21 (DGND), U12.27 (PGNDA), U12.29 (EPAD), U12.VIA1 (EPAD), U12.VIA2 (EPAD), U12.VIA3 (EPAD), U12.VIA4 (EPAD), U12.VIA5 (EPAD), U12.VIA6 (EPAD), U12.VIA7 (EPAD), U12.VIA8 (EPAD), U12.VIA9 (EPAD), U12.VIA10 (EPAD), U12.VIA11 (EPAD), U13.5 (ADCIN), U13.9 (AGND), U13.13 (PGNDB), U13.21 (DGND), U13.27 (PGNDA), U13.29 (EPAD), U13.VIA1 (EPAD), U13.VIA2 (EPAD), U13.VIA3 (EPAD), U13.VIA4 (EPAD), U13.VIA5 (EPAD), U13.VIA6 (EPAD), U13.VIA7 (EPAD), U13.VIA8 (EPAD), U13.VIA9 (EPAD), U13.VIA10 (EPAD), U13.VIA11 (EPAD), U14.5 (ADCIN), U14.9 (AGND), U14.13 (PGNDB), U14.21 (DGND), U14.27 (PGNDA), U14.29 (EPAD), U14.VIA1 (EPAD), U14.VIA2 (EPAD), U14.VIA3 (EPAD), U14.VIA4 (EPAD), U14.VIA5 (EPAD), U14.VIA6 (EPAD), U14.VIA7 (EPAD), U14.VIA8 (EPAD), U14.VIA9 (EPAD), U14.VIA10 (EPAD), U14.VIA11 (EPAD); also elsewhere on the board
L6470_CS: U7.23 (CSN), U8.23 (CSN), U9.23 (CSN), U10.23 (CSN), U11.23 (CSN), U12.23 (CSN), U13.23 (CSN), U14.23 (CSN); also elsewhere on the board
L6470_MISO: U14.18 (SDO); also elsewhere on the board
L6470_MOSI: U7.20 (SDI); also elsewhere on the board
L6470_RST: U7.3 (STBYN/RESETN), U8.3 (STBYN/RESETN), U9.3 (STBYN/RESETN), U10.3 (STBYN/RESETN), U11.3 (STBYN/RESETN), U12.3 (STBYN/RESETN), U13.3 (STBYN/RESETN), U14.3 (STBYN/RESETN); also elsewhere on the board
L6470_SCK: U7.19 (CK), U8.19 (CK), U9.19 (CK), U10.19 (CK), U11.19 (CK), U12.19 (CK), U13.19 (CK), U14.19 (CK); also elsewhere on the board
unnamed: C41.2, U7.10 (CP)
unnamed: C41.1, D2.3 (COM)
unnamed: C66.1, D2.2 (C2), U7.11 (VBOOT)
unnamed: R9.1, U7.4 (SW)
unnamed: BUSY1.A, RN6.8 (2)
unnamed: FLAG1.A, RN6.7 (2)
unnamed: C45.2, CN5.2, R9.2
unnamed: CN1.1, J3.1, U7.1 (OUT1A)
unnamed: CN1.2, J3.2, U7.28 (OUT2A)
unnamed: CN1.4, J3.4, U7.14 (OUT1B)
unnamed: CN1.3, J3.3, U7.15 (OUT2B)
unnamed: TP12.P$1, U7.18 (SDO), U8.20 (SDI)
unnamed: C42.2, U8.10 (CP)
unnamed: C42.1, D3.3 (COM)
unnamed: C68.1, D3.2 (C2), U8.11 (VBOOT)
unnamed: R10.1, U8.4 (SW)
unnamed: BUSY2.A, RN6.5 (2)
unnamed: FLAG2.A, RN6.6 (2)
unnamed: C46.2, CN6.2, R10.2
unnamed: CN2.1, J4.1, U8.1 (OUT1A)
unnamed: CN2.2, J4.2, U8.28 (OUT2A)
unnamed: CN2.4, J4.4, U8.14 (OUT1B)
unnamed: CN2.3, J4.3, U8.15 (OUT2B)
unnamed: TP13.P$1, U8.18 (SDO), U9.20 (SDI)
unnamed: C43.2, U9.10 (CP)
unnamed: C43.1, D4.3 (COM)
unnamed: C70.1, D4.2 (C2), U9.11 (VBOOT)
unnamed: R11.1, U9.4 (SW)
unnamed: BUSY3.A, RN7.8 (2)
unnamed: FLAG3.A, RN7.7 (2)
unnamed: C47.2, CN7.2, R11.2
unnamed: CN3.1, J5.1, U9.1 (OUT1A)
unnamed: CN3.2, J5.2, U9.28 (OUT2A)
unnamed: CN3.4, J5.4, U9.14 (OUT1B)
unnamed: CN3.3, J5.3, U9.15 (OUT2B)
unnamed: TP14.P$1, U9.18 (SDO), U10.20 (SDI)
unnamed: C44.2, U10.10 (CP)
unnamed: C44.1, D5.3 (COM)
unnamed: C72.1, D5.2 (C2), U10.11 (VBOOT)
unnamed: R12.1, U10.4 (SW)
unnamed: BUSY4.A, RN7.5 (2)
unnamed: FLAG4.A, RN7.6 (2)
unnamed: C48.2, CN8.2, R12.2
unnamed: CN4.1, J6.1, U10.1 (OUT1A)
unnamed: CN4.2, J6.2, U10.28 (OUT2A)
unnamed: CN4.4, J6.4, U10.14 (OUT1B)
unnamed: CN4.3, J6.3, U10.15 (OUT2B)
unnamed: TP15.P$1, U10.18 (SDO), U11.20 (SDI)
unnamed: C81.2, U11.10 (CP)
unnamed: C81.1, D6.3 (COM)
unnamed: C106.1, D6.2 (C2), U11.11 (VBOOT)
unnamed: R13.1, U11.4 (SW)
unnamed: BUSY5.A, RN8.8 (2)
unnamed: FLAG5.A, RN8.7 (2)
unnamed: C85.2, CN13.2, R13.2
unnamed: CN9.1, J7.1, U11.1 (OUT1A)
unnamed: CN9.2, J7.2, U11.28 (OUT2A)
unnamed: CN9.4, J7.4, U11.14 (OUT1B)
unnamed: CN9.3, J7.3, U11.15 (OUT2B)
unnamed: TP16.P$1, U11.18 (SDO), U12.20 (SDI)
unnamed: C82.2, U12.10 (CP)
unnamed: C82.1, D7.3 (COM)
unnamed: C108.1, D7.2 (C2), U12.11 (VBOOT)
unnamed: R14.1, U12.4 (SW)
unnamed: BUSY6.A, RN8.5 (2)
unnamed: FLAG6.A, RN8.6 (2)
unnamed: C86.2, CN14.2, R14.2
unnamed: CN10.1, J8.1, U12.1 (OUT1A)
unnamed: CN10.2, J8.2, U12.28 (OUT2A)
unnamed: CN10.4, J8.4, U12.14 (OUT1B)
unnamed: CN10.3, J8.3, U12.15 (OUT2B)
unnamed: TP17.P$1, U12.18 (SDO), U13.20 (SDI)
unnamed: C83.2, U13.10 (CP)
unnamed: C83.1, D8.3 (COM)
unnamed: C110.1, D8.2 (C2), U13.11 (VBOOT)
unnamed: R15.1, U13.4 (SW)
unnamed: BUSY7.A, RN9.8 (2)
unnamed: FLAG7.A, RN9.7 (2)
unnamed: C87.2, CN15.2, R15.2
unnamed: CN11.1, J9.1, U13.1 (OUT1A)
unnamed: CN11.2, J9.2, U13.28 (OUT2A)
unnamed: CN11.4, J9.4, U13.14 (OUT1B)
unnamed: CN11.3, J9.3, U13.15 (OUT2B)
unnamed: TP18.P$1, U13.18 (SDO), U14.20 (SDI)
unnamed: C84.2, U14.10 (CP)
unnamed: C84.1, D9.3 (COM)
unnamed: C112.1, D9.2 (C2), U14.11 (VBOOT)
unnamed: R16.1, U14.4 (SW)
unnamed: BUSY8.A, RN9.5 (2)
unnamed: FLAG8.A, RN9.6 (2)
unnamed: C88.2, CN16.2, R16.2
unnamed: CN12.1, J10.1, U14.1 (OUT1A)
unnamed: CN12.2, J10.2, U14.28 (OUT2A)
unnamed: CN12.4, J10.4, U14.14 (OUT1B)
unnamed: CN12.3, J10.3, U14.15 (OUT2B)
OSCOUT2: U7.8 (OSCOUT), U8.7 (OSCIN)
OSCOUT4: U8.8 (OSCOUT), U9.7 (OSCIN)
OSCOUT6: U9.8 (OSCOUT), U10.7 (OSCIN)
OSCOUT8: U10.8 (OSCOUT), U11.7 (OSCIN)
OSCOUT10: U11.8 (OSCOUT), U12.7 (OSCIN)
OSCOUT12: U12.8 (OSCOUT), U13.7 (OSCIN)
OSCOUT14: U13.8 (OSCOUT), U14.7 (OSCIN)
OSCOUT16: U14.8 (OSCOUT)
QGOUT1: Q3.3 (OUT), U7.7 (OSCIN)

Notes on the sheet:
Switch Input

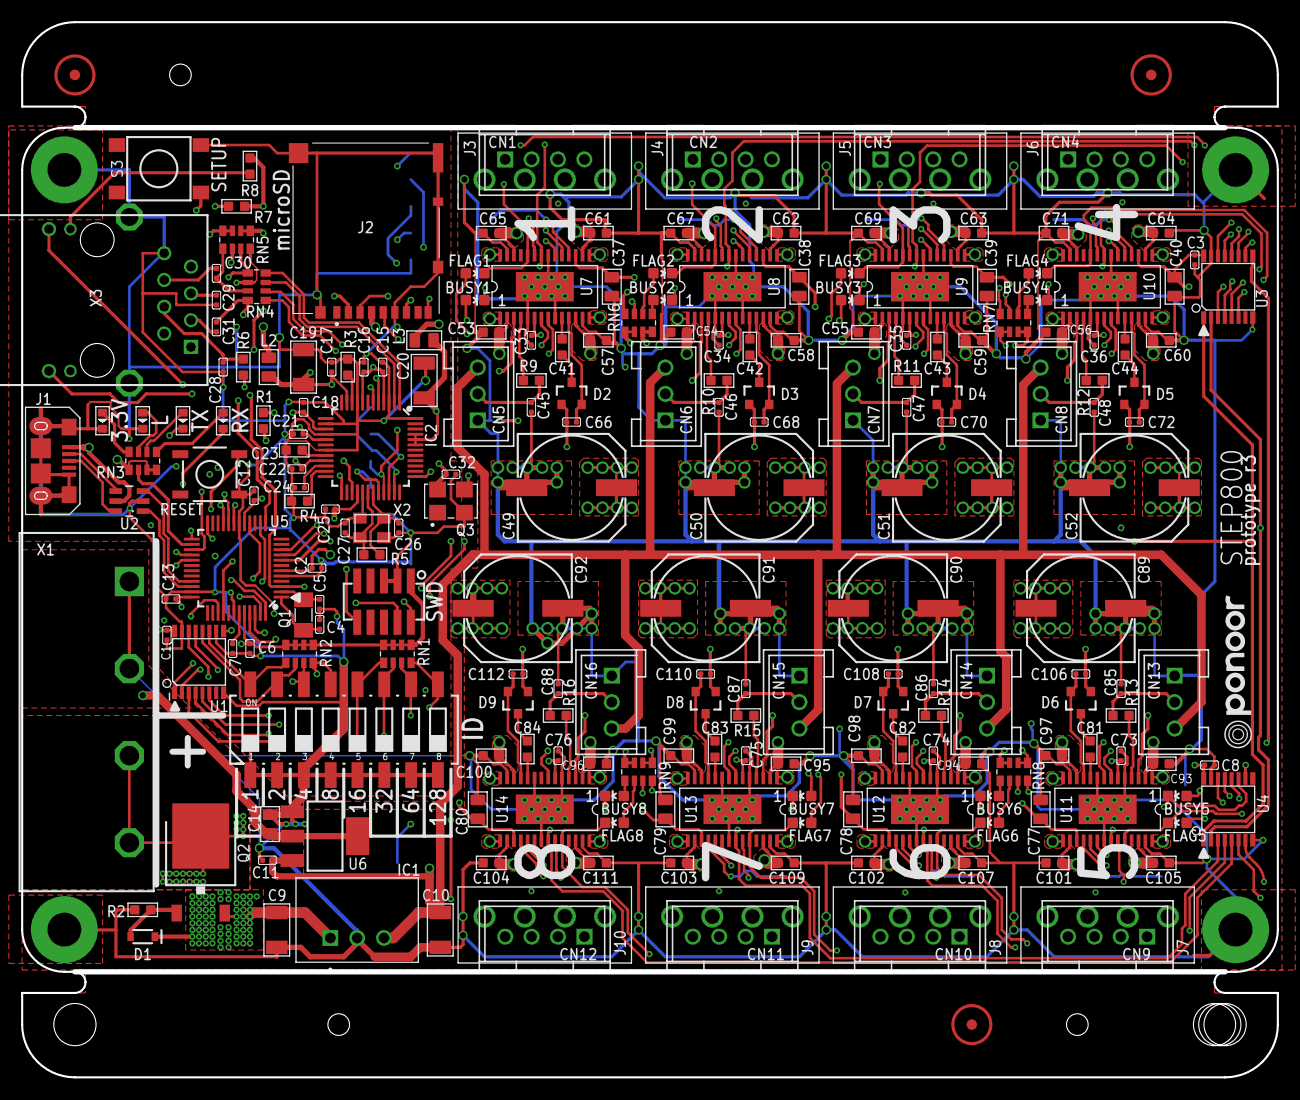
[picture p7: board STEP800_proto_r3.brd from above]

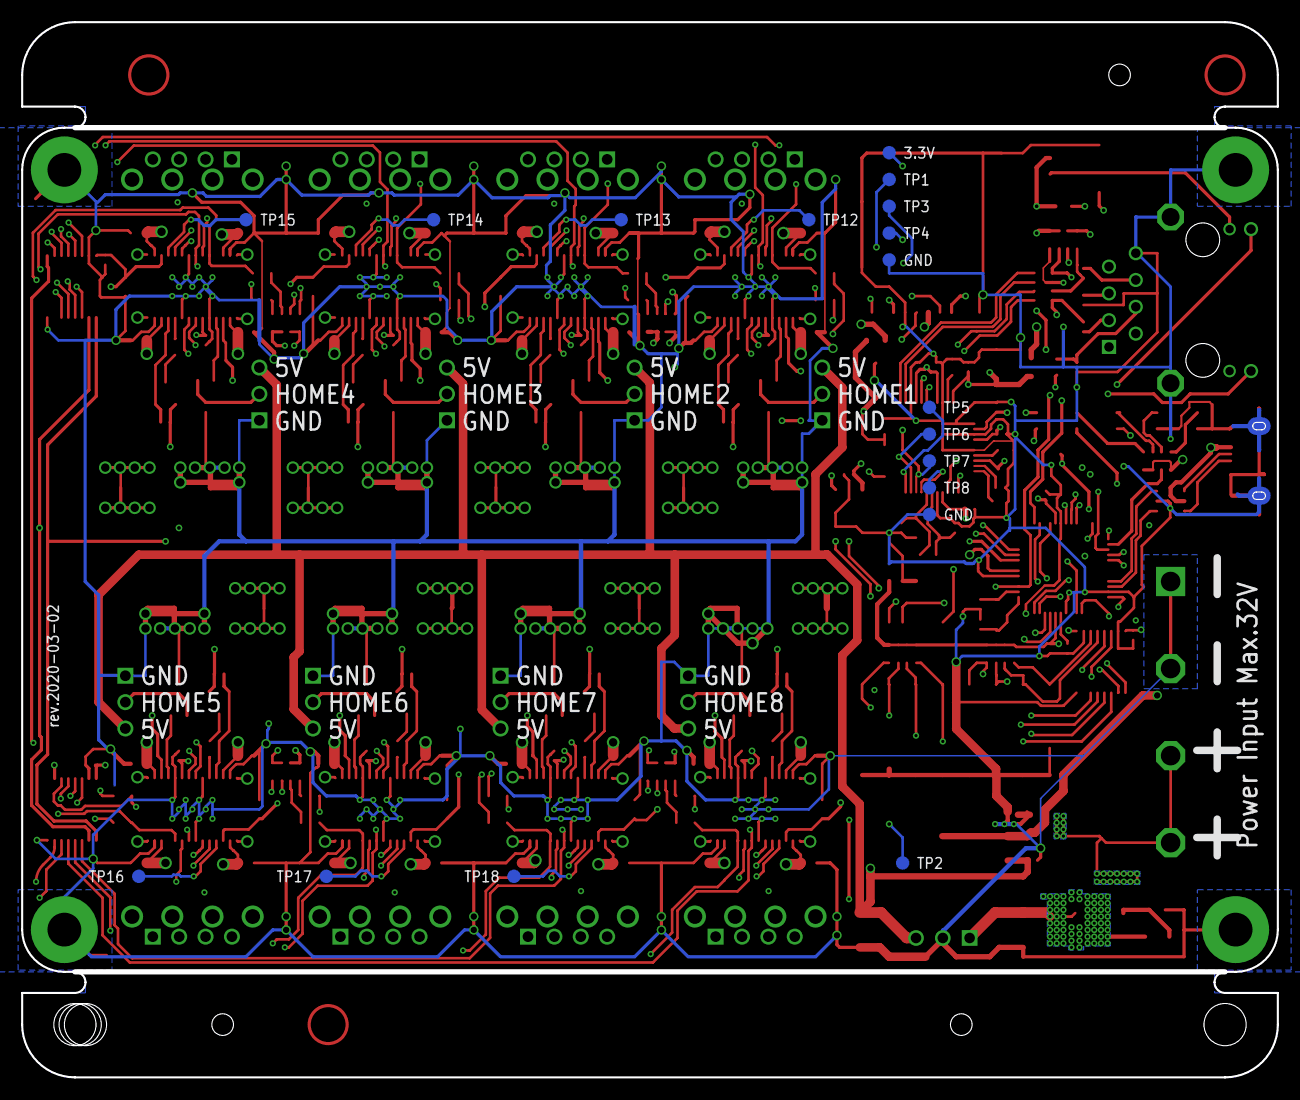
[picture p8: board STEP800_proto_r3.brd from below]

Board: 4 copper layers, 119.0 x 100.0 mm, 246 parts (18 on the bottom side), 200 nets.

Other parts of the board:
U$2: PONOOR_TEXT_15MM

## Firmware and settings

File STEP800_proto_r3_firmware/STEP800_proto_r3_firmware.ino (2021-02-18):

/*
 Name:		STEP800_proto_r3_firmware.ino

 target:    Arduino Zero
 Created:	2020/06/15 16:23:30
 Author:	kanta
*/

#include <Arduino.h>
#include "wiring_private.h" // pinPeripheral() function
//#include "samd.h" // for code sense @ Atmel Studio
#include <SPI.h>
#include <OSCMessage.h>
#include <Ethernet.h>
#include <SparkFundSPINConstants.h>
#include <SparkFunAutoDriver.h>

#define COMPILE_DATE __DATE__
#define COMPILE_TIME __TIME__
constexpr auto PROJECT_NAME = "STEP800proto_r3";

#define NUM_OF_MOTOR (8)

#define MOTOR_ID_ALL 255
#define MOTOR_ID_FIRST 1
#define MOTOR_ID_LAST 8

#define ledPin	13
byte mac[] = { 0x60, 0x95, 0xCE, 0x10, 0x03, 0x00 },
myId = 0;
#define IP_OFFSET	100
IPAddress myIp(10, 0, 0, IP_OFFSET);
IPAddress destIp(10, 0, 0, 10);
unsigned int outPort = 50100;
unsigned int inPort = 50000;

EthernetUDP Udp;
boolean isDestIpSet = false;
#define W5500_RESET_PIN A3

// STATUS register polling
#define STATUS_POLL_PERIOD   10	//[ms]

// these values will be initialized at setup()
bool busy[NUM_OF_MOTOR];
bool flag[NUM_OF_MOTOR];
bool HiZ[NUM_OF_MOTOR];
bool homeSwState[NUM_OF_MOTOR];
bool dir[NUM_OF_MOTOR];
bool uvloStatus[NUM_OF_MOTOR];
uint8_t motorStatus[NUM_OF_MOTOR];
uint8_t thermalStatus[NUM_OF_MOTOR];

bool reportBUSY[NUM_OF_MOTOR];
bool reportFLAG[NUM_OF_MOTOR];
bool reportHiZ[NUM_OF_MOTOR];
bool reportHomeSwStatus[NUM_OF_MOTOR];
bool reportDir[NUM_OF_MOTOR];
bool reportMotorStatus[NUM_OF_MOTOR];

bool reportSwEvn[NUM_OF_MOTOR];
bool reportCommandError[NUM_OF_MOTOR];
bool reportUVLO[NUM_OF_MOTOR];
bool reportThermalStatus[NUM_OF_MOTOR];
bool reportOCD[NUM_OF_MOTOR];
bool reportStall[NUM_OF_MOTOR];

// 74HC165 shift register for dip switch and busy/flag input
#define MISO3	3 // SERCOM2/PAD[1]
#define MOSI3	4 // SERCOM2/PAD[0] // dummy
#define SCK3	0 // SERCOM2/PAD[3]
#define LATCH3	A5
SPIClass SPI3(&sercom2, MISO3, SCK3, MOSI3, SPI_PAD_0_SCK_3, SERCOM_RX_PAD_1);
byte shiftResistorValue[3];

// L6470
#define L6470_MISO	6	// D6 /SERCOM3/PAD[2] miso
#define L6470_MOSI	11	// D11/SERCOM3/PAD[0] mosi
#define L6470_SCK	12	// D12/SERCOM3/PAD[3] sck
//SPIClass altSPI (&sercom1, 12, 13, 11, SPI_PAD_0_SCK_1, SERCOM_RX_PAD_3);
SPIClass L6470SPI(&sercom3, L6470_MISO, L6470_SCK, L6470_MOSI, SPI_PAD_0_SCK_3, SERCOM_RX_PAD_2);// MISO/SCK/MOSI pins

#define L6470_CS_PIN A0
#define L6470_RESET_PIN A2

AutoDriver stepper[] = {
	AutoDriver(7, L6470_CS_PIN, L6470_RESET_PIN),
	AutoDriver(6, L6470_CS_PIN, L6470_RESET_PIN),
	AutoDriver(5, L6470_CS_PIN, L6470_RESET_PIN),
	AutoDriver(4, L6470_CS_PIN, L6470_RESET_PIN),
	AutoDriver(3, L6470_CS_PIN, L6470_RESET_PIN),
	AutoDriver(2, L6470_CS_PIN, L6470_RESET_PIN),
	AutoDriver(1, L6470_CS_PIN, L6470_RESET_PIN),
	AutoDriver(0, L6470_CS_PIN, L6470_RESET_PIN)
};

// microSD slot
#define SD_CS_PIN	4u
#define SD_DETECT_PIN	A4

#define SETUP_SW_PIN	5u

// servo mode
uint32_t lastServoUpdateTime;
int32_t targetPosition[NUM_OF_MOTOR]; // these values will be initialized at setup()
float kP[NUM_OF_MOTOR], kI[NUM_OF_MOTOR], kD[NUM_OF_MOTOR];
boolean isServoMode[NUM_OF_MOTOR];
constexpr auto position_tolerance = 20; // steps

// Tx, Rx LED
bool rxLedEnabled = false, txLedEnabled = false;
uint32_t RXL_blinkStartTime, TXL_blinkStartTime;
#define RXL_TXL_BLINK_DURATION	100 // ms

void setUSBPriority()
{
	const auto irqn = USB_IRQn;
	NVIC_DisableIRQ(irqn);
	NVIC_SetPriority(irqn, 2);
	NVIC_EnableIRQ(irqn);
}

void setup()
{
	//setUSBPriority();
	pinMode(ledPin, OUTPUT);
	pinMode(SD_CS_PIN, OUTPUT);
	pinMode(LATCH3, OUTPUT);
	pinMode(SD_DETECT_PIN, INPUT_PULLUP);
	pinMode(SETUP_SW_PIN, INPUT_PULLUP);

	SerialUSB.begin(115200);

	pinMode(W5500_RESET_PIN, OUTPUT);

	// Prepare pins
	pinMode(L6470_RESET_PIN, OUTPUT);
	pinMode(L6470_CS_PIN, OUTPUT);
	pinMode(L6470_MOSI, OUTPUT);
	pinMode(L6470_MISO, INPUT);
	pinMode(L6470_SCK, OUTPUT);

	// Shift registers
	SPI3.begin();
	pinPeripheral(MISO3, PIO_SERCOM_ALT);	// MISO
	//pinPeripheral(MOSI3, PIO_SERCOM_ALT);	// MOSI, not in use
	pinPeripheral(SCK3, PIO_SERCOM_ALT);		// SCK
	SPI3.beginTransaction(SPISettings(4000000, MSBFIRST, SPI_MODE0));
	pinMode(LATCH3, OUTPUT);
	digitalWrite(LATCH3, HIGH);

	// Reset powerSTEP and set CS
	digitalWrite(L6470_RESET_PIN, HIGH);
	digitalWrite(L6470_RESET_PIN, LOW);
	delay(10);
	digitalWrite(L6470_RESET_PIN, HIGH);
	digitalWrite(L6470_CS_PIN, HIGH);

	// Start SPI for L6470
	L6470SPI.begin();
	pinPeripheral(L6470_MOSI, PIO_SERCOM_ALT);
	pinPeripheral(L6470_SCK, PIO_SERCOM_ALT);
	pinPeripheral(L6470_MISO, PIO_SERCOM_ALT);
	L6470SPI.setDataMode(SPI_MODE3);
	delay(10);

	// Configure L6470 and some variables
	for (uint8_t i = 0; i < NUM_OF_MOTOR; i++)
	{
		busy[i] = false;
		flag[i] = false;
		HiZ[i] = false;
		homeSwState[i] = false;
		dir[i] = false;
		uvloStatus[i] = false;
		motorStatus[i] = 0;
		thermalStatus[i] = 0;

		reportBUSY[i] = false;
		reportFLAG[i] = false;
		reportHiZ[i] = false;
		reportHomeSwStatus[i] = false;
		reportDir[i] = false;
		reportMotorStatus[i] = false;
		reportSwEvn[i] = false;
		reportCommandError[i] = false;
		reportUVLO[i] = false;
		reportThermalStatus[i] = false;
		reportOCD[i] = false;
		reportStall[i] = false;

		targetPosition[i] = 0;
		kP[i] = 0.06f;
		kI[i] = 0.0f;
		kD[i] = 0.0f;
		isServoMode[i] = false;

		stepper[i].SPIPortConnect(&L6470SPI);
		resetMotorDriver(i + MOTOR_ID_FIRST);
		digitalWrite(ledPin, HIGH);
		delay(20);
		digitalWrite(ledPin, LOW);
		delay(20);
	}

	// Configure W5500
	digitalWrite(W5500_RESET_PIN, HIGH);
	hasShiftRegisterUpdated();
	myId = shiftResistorValue[2];// shiftResistorValue[2];
	delay(1);
	resetEthernet();
}

void resetEthernet() {
	digitalWrite(W5500_RESET_PIN, LOW);
	digitalWrite(ledPin, HIGH);
	delay(10); // This delay is necessary to refresh the network connection.
	digitalWrite(W5500_RESET_PIN, HIGH);
	digitalWrite(ledPin, LOW);
	delay(1);
	mac[5] = IP_OFFSET + myId;
	myIp[3] = IP_OFFSET + myId;
	outPort = 50000 + IP_OFFSET + myId;
	Ethernet.begin(mac, myIp);
	Udp.begin(inPort);
}

void resetMotorDriver(uint8_t deviceID) {
	if (MOTOR_ID_FIRST <= deviceID && deviceID <= MOTOR_ID_LAST) {
		deviceID -= MOTOR_ID_FIRST;
		stepper[deviceID].resetDev();
		stepper[deviceID].configStepMode(STEP_FS_128);
		stepper[deviceID].setMaxSpeed(650.);
		stepper[deviceID].setLoSpdOpt(true);
		stepper[deviceID].setFullSpeed(15000.);
		stepper[deviceID].setAcc(2000.);
		stepper[deviceID].setDec(2000.);
		stepper[deviceID].setSlewRate(SR_530V_us);
		stepper[deviceID].setOCThreshold(OC_1500mA);
		stepper[deviceID].setOCShutdown(OC_SD_ENABLE);
		stepper[deviceID].setPWMFreq(PWM_DIV_1, PWM_MUL_0_75);
		stepper[deviceID].setVoltageComp(VS_COMP_DISABLE);
		stepper[deviceID].hardHiZ();
		stepper[deviceID].setSwitchMode(SW_USER);
		stepper[deviceID].setOscMode(EXT_16MHZ_OSCOUT_INVERT);
		stepper[deviceID].setRunKVAL(64);
		stepper[deviceID].setAccKVAL(64);
		stepper[deviceID].setDecKVAL(64);
		stepper[deviceID].setHoldKVAL(32);
		stepper[deviceID].setParam(STALL_TH, 0x1F);
		stepper[deviceID].setParam(ALARM_EN, 0xFF);
		delay(1);
		stepper[deviceID].getStatus(); // clears error flags
	}
}

void turnOnRXL() {
	digitalWrite(PIN_LED_RXL, LOW); // turn on
	RXL_blinkStartTime = millis();
	rxLedEnabled = true;
}

void turnOnTXL() {
	digitalWrite(PIN_LED_TXL, LOW); // turn on
	TXL_blinkStartTime = millis();
	txLedEnabled = true;
}

/************************* float -> int cast helper for OSC message ****************************/
int getInt(OSCMessage &msg, uint8_t offset)
{
	int msgVal = 0;
	if (msg.isFloat(offset))
	{
		msgVal = (int) msg.getFloat(offset);
	}
	else
	{
		msgVal = msg.getInt(offset);
	}
	return msgVal;
}


void sendOneInt(char* address, int32_t data) {
	if (!isDestIpSet) { return; }
	OSCMessage newMes(address);
	newMes.add((int32_t)data);
	Udp.beginPacket(destIp, outPort);
	newMes.send(Udp);
	Udp.endPacket();
	newMes.empty();
	turnOnTXL();
}

void sendTwoInt(char* address, int32_t data1, int32_t data2) {
	if (!isDestIpSet) { return; }
	OSCMessage newMes(address);
	newMes.add((int32_t)data1).add((int32_t)data2);
	Udp.beginPacket(destIp, outPort);
	newMes.send(Udp);
	Udp.endPacket();
	newMes.empty();
	turnOnTXL();
}

void sendIdFloat(char* address, int32_t id, float data) {
	if (!isDestIpSet) { return; }
	OSCMessage newMes(address);
	newMes.add(id).add(data);
	Udp.beginPacket(destIp, outPort);
	newMes.send(Udp);
	Udp.endPacket();
	newMes.empty();
	turnOnTXL();
}

void sendOneString(char* address, const char* data) {
	OSCMessage newMes(address);
	newMes.add(data);
	Udp.beginPacket(destIp, outPort);
	newMes.send(Udp);
	Udp.endPacket();
	newMes.empty();
	turnOnTXL();
}

#pragma region config_commands_osc_listener
void setDestIp(OSCMessage& msg, int addrOffset) {
	bool bIpUpdated = false;
	OSCMessage newMes("/destIp");
	for (auto i = 0; i < 4; i++)
	{
		bIpUpdated |= (destIp[i] != Udp.remoteIP()[i]);
		newMes.add(Udp.remoteIP()[i]);
	}
	destIp = Udp.remoteIP();
	newMes.add(bIpUpdated);
	Udp.beginPacket(destIp, outPort);
	newMes.send(Udp);
	Udp.endPacket();
	newMes.empty();
	isDestIpSet = true;
	turnOnTXL();
}

void getVersion(OSCMessage& msg, int addrOffset) {
	String version = COMPILE_DATE;
	version += String(" ") + String(COMPILE_TIME) + String(" ") + String(PROJECT_NAME);
	sendOneString("/version", version.c_str());
}

// reset the motor driver chip and setup it
void resetMotorDriver(OSCMessage& msg, int addrOffset) {
	uint8_t motorID = getInt(msg, 0);
	if (MOTOR_ID_FIRST <= motorID && motorID <= MOTOR_ID_LAST) {
		resetMotorDriver(motorID);
	}
	else if (motorID == MOTOR_ID_ALL) {
		for (uint8_t i = 0; i < NUM_OF_MOTOR; i++) {
			resetMotorDriver(i);
		}
	}
}

// simply send reset command to the driverchip via SPI
void resetDev(OSCMessage& msg, int addrOffset) {
	uint8_t motorID = getInt(msg, 0);
	if (MOTOR_ID_FIRST <= motorID && motorID <= MOTOR_ID_LAST) {
		stepper[motorID - MOTOR_ID_FIRST].resetDev();
	}
	else if (motorID == MOTOR_ID_ALL) {
		for (uint8_t i = 0; i < NUM_OF_MOTOR; i++) {
			stepper[i].resetDev();
		}
	}
}

void enableFlagReport(OSCMessage& msg, int addrOffset) {
	uint8_t motorID = getInt(msg, 0);
	bool bEnable = getInt(msg, 1) > 0;
	if (MOTOR_ID_FIRST <= motorID && motorID <= MOTOR_ID_LAST) {
		reportFLAG[motorID - 1] = bEnable;
	}
	else if (motorID == MOTOR_ID_ALL) {
		for (uint8_t i = 0; i < NUM_OF_MOTOR; i++) {
			reportFLAG[i] = bEnable;
		}
	}
}

void enableBusyReport(OSCMessage& msg, int addrOffset) {
	uint8_t motorID = getInt(msg, 0);
	bool bEnable = getInt(msg, 1) > 0;
	if (MOTOR_ID_FIRST <= motorID && motorID <= MOTOR_ID_LAST) {
		reportBUSY[motorID - 1] = bEnable;
	}
	else if (motorID == MOTOR_ID_ALL) {
		for (uint8_t i = 0; i < NUM_OF_MOTOR; i++) {
			reportBUSY[i] = bEnable;
		}
	}
}

void enableHizReport(OSCMessage& msg, int addrOffset) {
	uint8_t motorID = getInt(msg, 0);
	bool bEnable = getInt(msg, 1) > 0;
	if (MOTOR_ID_FIRST <= motorID && motorID <= MOTOR_ID_LAST) {
		reportHiZ[motorID - 1] = bEnable;
	}
	else if (motorID == MOTOR_ID_ALL) {
		for (uint8_t i = 0; i < NUM_OF_MOTOR; i++) {
			reportHiZ[i] = bEnable;
		}
	}
}
void enableHomeSwReport(OSCMessage& msg, int addrOffset) {
	uint8_t motorID = getInt(msg, 0);
	bool bEnable = getInt(msg, 1) > 0;
	if (MOTOR_ID_FIRST <= motorID && motorID <= MOTOR_ID_LAST) {
		reportHomeSwStatus[motorID - 1] = bEnable;
	}
	else if (motorID == MOTOR_ID_ALL) {
		for (uint8_t i = 0; i < NUM_OF_MOTOR; i++) {
			reportHomeSwStatus[i] = bEnable;
		}
	}
}
void enableDirReport(OSCMessage& msg, int addrOffset) {
	uint8_t motorID = getInt(msg, 0);
	bool bEnable = getInt(msg, 1) > 0;
	if (MOTOR_ID_FIRST <= motorID && motorID <= MOTOR_ID_LAST) {
		reportDir[motorID - 1] = bEnable;
	}
	else if (motorID == MOTOR_ID_ALL) {
		for (uint8_t i = 0; i < NUM_OF_MOTOR; i++) {
			reportDir[i] = bEnable;
		}
	}
}
void enableMotorStatusReport(OSCMessage& msg, int addrOffset) {
	uint8_t motorID = getInt(msg, 0);
	bool bEnable = getInt(msg, 1) > 0;
	if (MOTOR_ID_FIRST <= motorID && motorID <= MOTOR_ID_LAST) {
		reportMotorStatus[motorID - 1] = bEnable;
	}
	else if (motorID == MOTOR_ID_ALL) {
		for (uint8_t i = 0; i < NUM_OF_MOTOR; i++) {
			reportMotorStatus[i] = bEnable;
		}
	}
}
void enableSwEventReport(OSCMessage& msg, int addrOffset) {
	uint8_t motorID = getInt(msg, 0);
	bool bEnable = getInt(msg, 1) > 0;
	if (MOTOR_ID_FIRST <= motorID && motorID <= MOTOR_ID_LAST) {
		reportSwEvn[motorID - 1] = bEnable;
	}
	else if (motorID == MOTOR_ID_ALL) {
		for (uint8_t i = 0; i < NUM_OF_MOTOR; i++) {
			reportSwEvn[i] = bEnable;
		}
	}
}
void enableCommandErrorReport(OSCMessage& msg, int addrOffset) {
	uint8_t motorID = getInt(msg, 0);
	bool bEnable = getInt(msg, 1) > 0;
	if (MOTOR_ID_FIRST <= motorID && motorID <= MOTOR_ID_LAST) {
		reportCommandError[motorID - 1] = bEnable;
	}
	else if (motorID == MOTOR_ID_ALL) {
		for (uint8_t i = 0; i < NUM_OF_MOTOR; i++) {
			reportCommandError[i] = bEnable;
		}
	}
}
void enableUvloReport(OSCMessage& msg, int addrOffset) {
	uint8_t motorID = getInt(msg, 0);
	bool bEnable = getInt(msg, 1) > 0;
	if (MOTOR_ID_FIRST <= motorID && motorID <= MOTOR_ID_LAST) {
		reportUVLO[motorID - 1] = bEnable;
	}
	else if (motorID == MOTOR_ID_ALL) {
		for (uint8_t i = 0; i < NUM_OF_MOTOR; i++) {
			reportUVLO[i] = bEnable;
		}
	}
}
void enableThermalStatusReport(OSCMessage& msg, int addrOffset) {
	uint8_t motorID = getInt(msg, 0);
	bool bEnable = getInt(msg, 1) > 0;
	if (MOTOR_ID_FIRST <= motorID && motorID <= MOTOR_ID_LAST) {
		reportThermalStatus[motorID - 1] = bEnable;
	}
	else if (motorID == MOTOR_ID_ALL) {
		for (uint8_t i = 0; i < NUM_OF_MOTOR; i++) {
			reportThermalStatus[i] = bEnable;
		}
	}
}
void enableOverCurrentReport(OSCMessage& msg, int addrOffset) {
	uint8_t motorID = getInt(msg, 0);
	bool bEnable = getInt(msg, 1) > 0;
	if (MOTOR_ID_FIRST <= motorID && motorID <= MOTOR_ID_LAST) {
		reportOCD[motorID - 1] = bEnable;
	}
	else if (motorID == MOTOR_ID_ALL) {
		for (uint8_t i = 0; i < NUM_OF_MOTOR; i++) {
			reportOCD[i] = bEnable;
		}
	}
}
void enableStallReport(OSCMessage& msg, int addrOffset) {
	// uint8_t motorID = msg.getInt(0);
	// bool bEnable = msg.getInt(1) > 0;
	uint8_t motorID = getInt(msg, 0);
	bool bEnable = getInt(msg, 1) > 0;
	if (MOTOR_ID_FIRST <= motorID && motorID <= MOTOR_ID_LAST)
	{
		reportStall[motorID - 1] = bEnable;
	}
	else if (motorID == MOTOR_ID_ALL) {
		for (uint8_t i = 0; i < NUM_OF_MOTOR; i++) {
			reportStall[i] = bEnable;
		}
	}
}

void getHomeSw(OSCMessage& msg, int addrOffset) {
	if (!isDestIpSet) { return; }
	uint8_t motorID = getInt(msg, 0);
	if (MOTOR_ID_FIRST <= motorID && motorID <= MOTOR_ID_LAST) {
		getHomeSw(motorID);
	}
	else if (motorID == MOTOR_ID_ALL) {
		for (uint8_t i = 0; i < NUM_OF_MOTOR; i++) {
			getHomeSw(i + 1);
		}
	}
}
void getHomeSw(uint8_t motorID) {
	if (!isDestIpSet) { return; }
	OSCMessage newMes("/homeSw");
	newMes.add(motorID).add(homeSwState[motorID - MOTOR_ID_FIRST]).add(dir[motorID - MOTOR_ID_FIRST]);
	Udp.beginPacket(destIp, outPort);
	newMes.send(Udp);
	Udp.endPacket();
	newMes.empty();
	turnOnTXL();
}

void getBusy(OSCMessage& msg, int addrOffset) {
	if (!isDestIpSet) { return; }
	uint8_t motorID = getInt(msg, 0);
	if (MOTOR_ID_FIRST <= motorID && motorID <= MOTOR_ID_LAST)
	{
		sendTwoInt("/busy", motorID, busy[motorID - MOTOR_ID_FIRST]);
	}
	else if (motorID == MOTOR_ID_ALL) {
		for (uint8_t i = 0; i < NUM_OF_MOTOR; i++) {
			sendTwoInt("/busy", i + MOTOR_ID_FIRST, busy[i]);
		}
	}
}
void getUvlo(OSCMessage& msg, int addrOffset) {
	if (!isDestIpSet) { return; }
	uint8_t motorID = getInt(msg, 0);
	if (MOTOR_ID_FIRST <= motorID && motorID <= MOTOR_ID_LAST) {
		sendTwoInt("/uvlo", motorID, uvloStatus[motorID - MOTOR_ID_FIRST]);
	}
	else if (motorID == MOTOR_ID_ALL) {
		for (uint8_t i = 0; i < NUM_OF_MOTOR; i++) {
			sendTwoInt("/uvlo", i + 1, uvloStatus[i]);
		}
	}
}

void getMotorStatus(OSCMessage& msg, int addrOffset) {
	if (!isDestIpSet) { return; }
	uint8_t motorID = getInt(msg, 0);
	if (MOTOR_ID_FIRST <= motorID && motorID <= MOTOR_ID_LAST)
	{
		sendTwoInt("/motorStatus", motorID, motorStatus[motorID - MOTOR_ID_FIRST]);
	}
	else if (motorID == MOTOR_ID_ALL) {
		for (uint8_t i = 0; i < NUM_OF_MOTOR; i++) {
			sendTwoInt("/motorStatus", i + 1, motorStatus[i]);
		}
	}
}

void getThermalStatus(OSCMessage& msg, int addrOffset) {
	if (!isDestIpSet) { return; }
	uint8_t motorID = getInt(msg, 0);
	if (MOTOR_ID_FIRST <= motorID && motorID <= MOTOR_ID_LAST) {
		sendTwoInt("/thermalStatus", motorID, thermalStatus[motorID - MOTOR_ID_FIRST]);
	}
	else if (motorID == MOTOR_ID_ALL) {
		for (uint8_t i = 0; i < NUM_OF_MOTOR; i++) {
			sendTwoInt("/thermalStatus", i + 1, thermalStatus[i]);
		}
	}
}

void getStatus(OSCMessage& msg, int addrOffset) {
	if (!isDestIpSet) { return; }
	uint8_t motorID = getInt(msg, 0);
	if (MOTOR_ID_FIRST <= motorID && motorID <= MOTOR_ID_LAST) {
		sendTwoInt("/status", motorID, stepper[motorID - MOTOR_ID_FIRST].getStatus());
	}
	else if (motorID == MOTOR_ID_ALL) {
		for (uint8_t i = 0; i < NUM_OF_MOTOR; i++) {
			sendTwoInt("/status", i + MOTOR_ID_FIRST, stepper[i].getStatus());
		}
	}
}

void getStatusList(OSCMessage& msg, int addrOffset) {
	if (!isDestIpSet) { return; }
	OSCMessage newMes("/statusList");
	for (uint8_t i = 0; i < NUM_OF_MOTOR; i++) {
		newMes.add((int32_t)stepper[i].getStatus());
	}

	Udp.beginPacket(destIp, outPort);
	newMes.send(Udp);
	Udp.endPacket();
	newMes.empty();
	turnOnTXL();
}

void setMicrostepMode(OSCMessage& msg, int addrOffset) {
	uint8_t motorID = getInt(msg, 0);
	uint8_t microstepMode = constrain(getInt(msg, 1), STEP_FS, STEP_FS_128); // 0-7

	if (MOTOR_ID_FIRST <= motorID && motorID <= MOTOR_ID_LAST) {
		stepper[motorID - MOTOR_ID_FIRST].configStepMode(microstepMode);
	}
	else if (motorID == MOTOR_ID_ALL) {
		for (uint8_t i = 0; i < NUM_OF_MOTOR; i++) {
			stepper[i].configStepMode(microstepMode);
		}
	}
}

void getMicrostepMode(OSCMessage& msg, int addrOffset) {
	if (!isDestIpSet) { return; }
	uint8_t motorID = getInt(msg, 0);

	if (MOTOR_ID_FIRST <= motorID && motorID <= MOTOR_ID_LAST) {
		sendTwoInt("/microstepMode", motorID, stepper[motorID - MOTOR_ID_FIRST].getStepMode());
	}
	else if (motorID == MOTOR_ID_ALL) {
		for (uint8_t i = 0; i < NUM_OF_MOTOR; i++) {
			sendTwoInt("/microstepMode", i + MOTOR_ID_FIRST, stepper[i].getStepMode());
		}
	}
}

void getHomeSwMode(OSCMessage& msg, int addrOffset) {
	if (!isDestIpSet) { return; }
	uint8_t motorID = getInt(msg, 0);
	if (MOTOR_ID_FIRST <= motorID && motorID <= MOTOR_ID_LAST) {
		sendTwoInt("/homeSwMode", motorID, stepper[motorID - MOTOR_ID_FIRST].getSwitchMode() > 0);
	}
	else if (motorID == MOTOR_ID_ALL) {
		for (uint8_t i = 0; i < NUM_OF_MOTOR; i++) {
			sendTwoInt("/homeSwMode", i + MOTOR_ID_FIRST, stepper[i].getSwitchMode() > 0);
		}
	}
}

void setHomeSwMode(OSCMessage& msg, int addrOffset) {
	uint8_t motorID = getInt(msg, 0);
	uint16_t switchMode = (getInt(msg, 1) > 0) ? SW_USER : SW_HARD_STOP;

	if (MOTOR_ID_FIRST <= motorID && motorID <= MOTOR_ID_LAST) {
		stepper[motorID - MOTOR_ID_FIRST].setSwitchMode(switchMode);
	}
	else if (motorID == MOTOR_ID_ALL) {
		for (uint8_t i = 0; i < NUM_OF_MOTOR; i++) {
			stepper[i].setSwitchMode(switchMode);
		}
	}
}

void setStallThreshold(OSCMessage& msg, int addrOffset) {
	uint8_t motorID = getInt(msg, 0);
	uint8_t threshold = getInt(msg, 1) & 0x7F; // 7bit

	if (MOTOR_ID_FIRST <= motorID && motorID <= MOTOR_ID_LAST) {
		stepper[motorID - MOTOR_ID_FIRST].setParam(STALL_TH, threshold);
		getStallThreshold(motorID);
	}
	else if (motorID == MOTOR_ID_ALL) {
		for (uint8_t i = 0; i < NUM_OF_MOTOR; i++) {
			stepper[i].setParam(STALL_TH, threshold);
			getStallThreshold(i + 1);
		}
	}
	
}
void getStallThreshold(uint8_t motorId) {
	if (!isDestIpSet) { return; }
	uint8_t stall_th_raw = stepper[motorId - MOTOR_ID_FIRST].getParam(STALL_TH) & 0x7F;
	float threshold = (stall_th_raw + 1) * 31.25;
	sendIdFloat("/stallThreshold", motorId, threshold);
}
void getStallThreshold(OSCMessage& msg, int addrOffset) {
	uint8_t motorID = getInt(msg, 0);
	if (MOTOR_ID_FIRST <= motorID && motorID <= MOTOR_ID_LAST) {
		getStallThreshold(motorID);
	}
	else if (motorID == MOTOR_ID_ALL) {
		for (uint8_t i = 0; i < NUM_OF_MOTOR; i++) {
			getStallThreshold(i + MOTOR_ID_FIRST);
		}
	}
}

void setOverCurrentThreshold(OSCMessage& msg, int addrOffset) {
	uint8_t motorID = getInt(msg, 0);
	uint8_t threshold = getInt(msg, 1) & 0x0F; // 4bit

	if (MOTOR_ID_FIRST <= motorID && motorID <= MOTOR_ID_LAST) {
		stepper[motorID - MOTOR_ID_FIRST].setParam(OCD_TH, threshold);
		getOverCurrentThreshold(motorID);
	}
	else if (motorID == MOTOR_ID_ALL) {
		for (uint8_t i = 0; i < NUM_OF_MOTOR; i++) {
			stepper[i].setParam(OCD_TH, threshold);
			getOverCurrentThreshold(i + 1);
		}
	}
}
void getOverCurrentThreshold(uint8_t motorId) {
	if (!isDestIpSet) { return; }
	uint8_t ocd_th_raw = stepper[motorId - MOTOR_ID_FIRST].getParam(OCD_TH) & 0x0F;
	float threshold = (ocd_th_raw + 1) * 375;
	sendIdFloat("/overCurrentThreshold", motorId, threshold);
}
void getOverCurrentThreshold(OSCMessage& msg, int addrOffset) {
	uint8_t motorID = getInt(msg, 0);
	if (MOTOR_ID_FIRST <= motorID && motorID <= MOTOR_ID_LAST) {
		getOverCurrentThreshold(motorID);
	}
	else if (motorID == MOTOR_ID_ALL) {
		for (uint8_t i = 0; i < NUM_OF_MOTOR; i++) {
			getOverCurrentThreshold(i + MOTOR_ID_FIRST);
		}
	}
}
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
void loop() {
	uint32_t currentTimeMillis = millis(),
		currentTimeMicros = micros();
	static uint32_t lastPollTime = 0;

	if ((uint32_t)(currentTimeMillis - lastPollTime) >= STATUS_POLL_PERIOD)
	{
		checkStatus();
		checkLED(currentTimeMillis);
		if (hasShiftRegisterUpdated()) {
			updateFlagBusy();
			updateMyId();
		}
		lastPollTime = currentTimeMillis;
	}
	OSCMsgReceive();

	updateServo(currentTimeMicros);
}

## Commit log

2020-07-10 update servo mode and AutoDriver library
2020-07-10 Variables initialization and constants name updated. Added hardware design files.
    [STEP800_proto_r3.brd, STEP800_proto_r3.sch]

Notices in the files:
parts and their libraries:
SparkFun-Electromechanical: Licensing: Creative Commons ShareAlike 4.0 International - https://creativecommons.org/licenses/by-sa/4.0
